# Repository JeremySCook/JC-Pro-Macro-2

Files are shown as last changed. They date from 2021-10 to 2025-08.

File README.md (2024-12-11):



# JC-Pro-Macro-2 Rotary Macro Keypad with GPIO Breakouts

JC Pro Macro 2 macro keyboard and rotary input, with GPIO breakouts. Uses an ATmega32u4 Pro Micro dev board for HID functionality.

Available now on Tindie: https://www.tindie.com/products/jeremycook/jc-pro-macro-2-rotarygpio-macro-keyboard-kit/

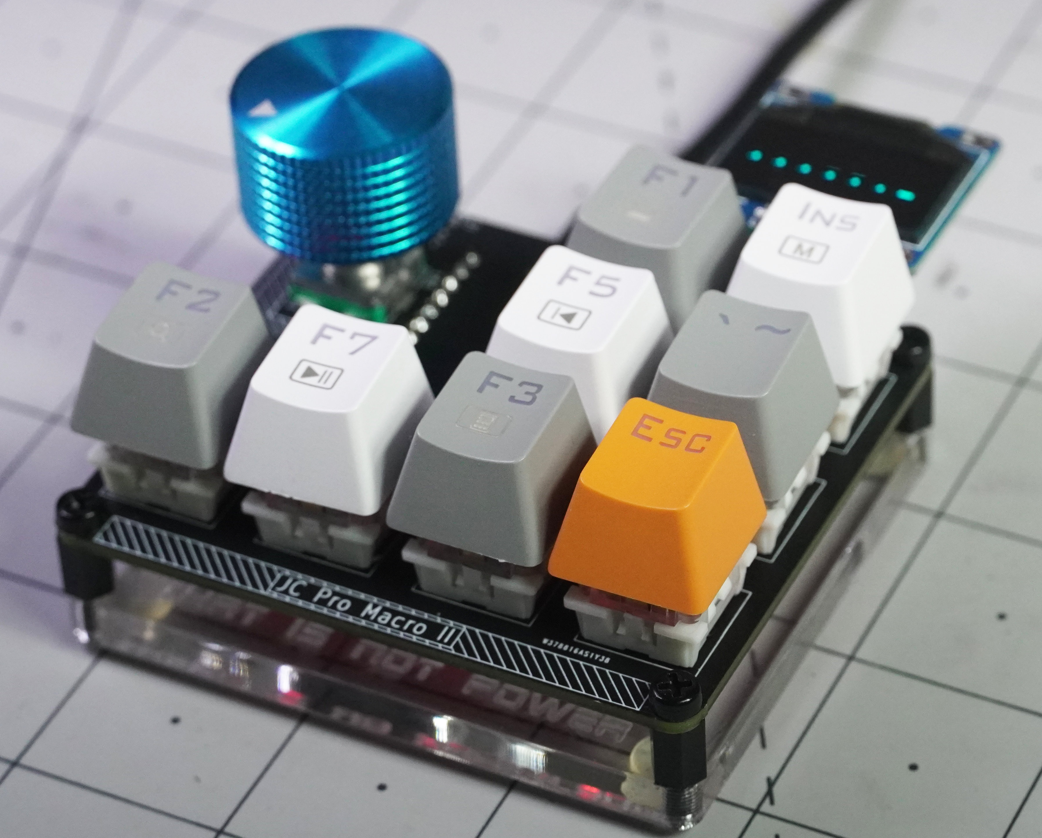
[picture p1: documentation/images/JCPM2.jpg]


Manual: https://github.com/JeremySCook/JC-Pro-Macro-2/tree/main/documentation  

# Intro Video (YouTube):

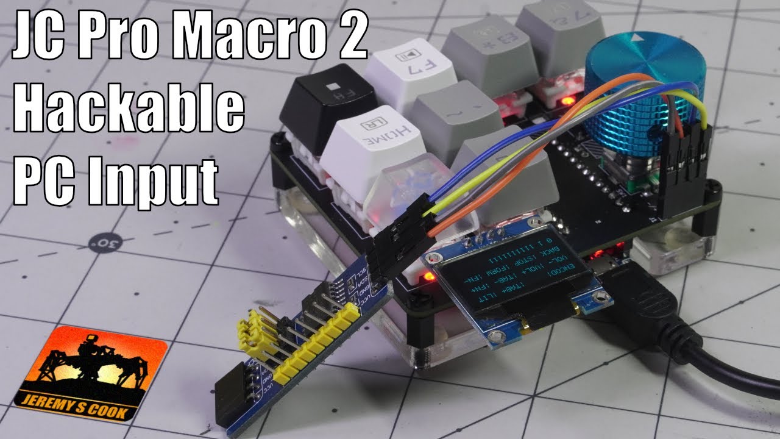
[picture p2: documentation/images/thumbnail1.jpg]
Watch the video (https://www.youtube.com/watch?v=Pz0toa3XK4c)




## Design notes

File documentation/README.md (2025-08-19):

# JCPM 2 User Manual #



If you’re viewing this page, you’ve likely either purchased, or are interested in a JC Pro Macro 2 mechanical shortcut keypad  
(funded on Kickstarter, available soon on Tindie). While it comes with several useful functions:

    • Standard Volume/media/fan control
    • Mouse Jiggler
    • FCPX Helper

The real power of this keyboard, however, is that you can customize it as you see fit.  
You don’t need any sort of program running on your computer to take advantage of it,  
as the computer simply sees it as a secondary keyboard and/or mouse. 

One could argue this makes it quite future proof, however, programming it, as of this writing, will  
require you to use the Arduino IDE. That being said, The design is extremely hackable, and I hope that  
others develop new ways to program and use it, perhaps which I’d never even thought of. This document  
will help you get started.

## Videos ##

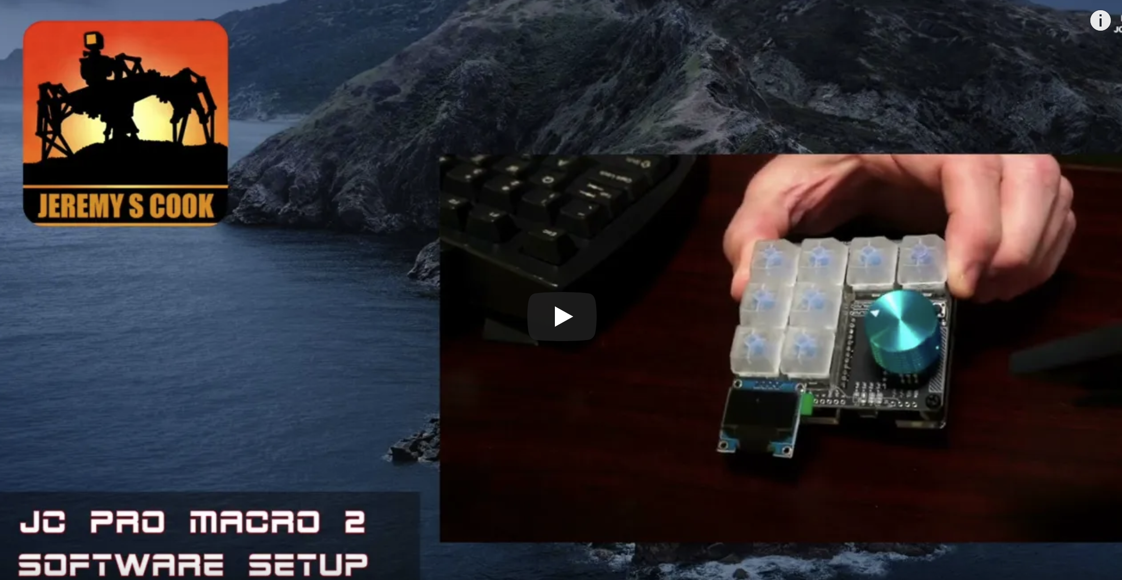
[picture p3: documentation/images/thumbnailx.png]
Watch the video (https://www.youtube.com/playlist?list=PLHdAqwjxcGeRL2wQRV785VI08VL_sdoh7)


## Basic Operation ##

If the JCPM2 came pre-programmed, plug it in via USB and wait a few seconds for it to become active.  
The rotary encoder will control a computer’s volume, while the bottom left three keys are for media control,  
and the two keys directly to the right of the encoder shift through browser tabs. The upper-right key switch  
controls lights under the pad, while the two below that are used to control an external PC-style fan or other  
small load. This can all be customized.

A smaller button on the left of the pad cycles through different modes, the first of which is a random  
mouse jiggler, used to keep a computer awake. The second is set up for Final Cut Pro X, which I enjoy immensely.  
Of course, this may not be useful for you, and can be bypassed in the program.

## Loading a Program ##

First install the Arduino IDE.

**Required Libraries:**

Once the Arduino IDE is installed, you’ll need to add a few libraries (supporting bits of code that you don’t  
directly see, but are used in the program). To do so, navigate to Tools > Manage Libraries, then search for and  
install the following:

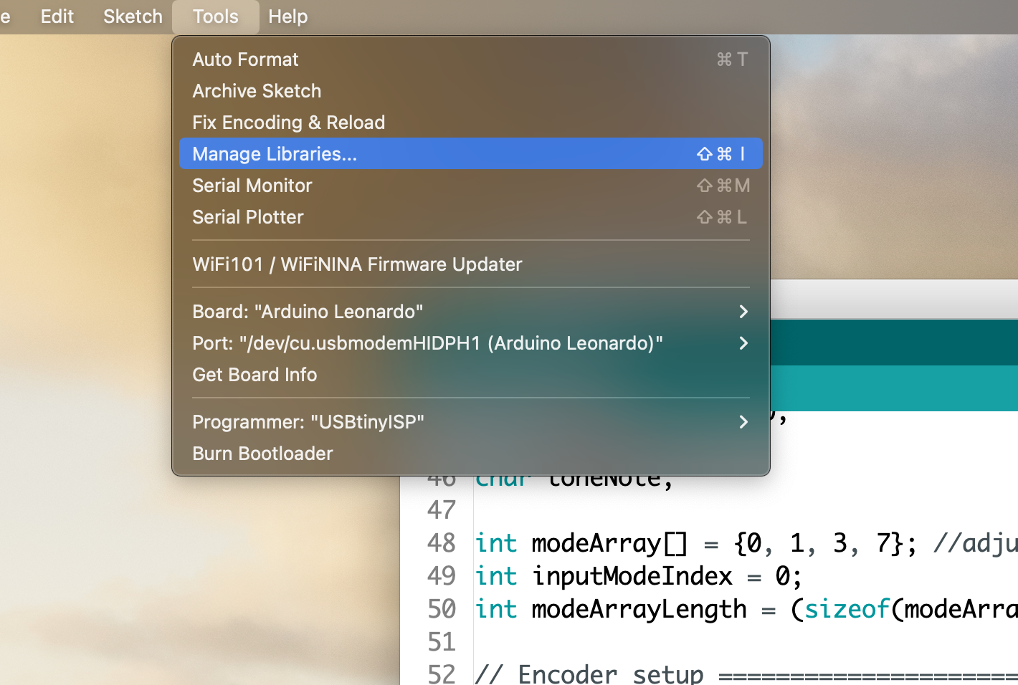
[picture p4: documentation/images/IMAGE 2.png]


    • Encoder (Paul Stoffregen): https://www.pjrc.com/teensy/td_libs_Encoder.html 
    • HID-Project (NicoHood): https://github.com/NicoHood/HID 
    • Adafruit_GFX Library (Adafruit): https://github.com/adafruit/Adafruit-GFX-Library
    • Adafruit SSD1306 (Adafruit): https://github.com/adafruit/Adafruit_SSD1306 
    • Adafruit NeoPixel (Adafruit): https://github.com/adafruit/Adafruit_NeoPixel

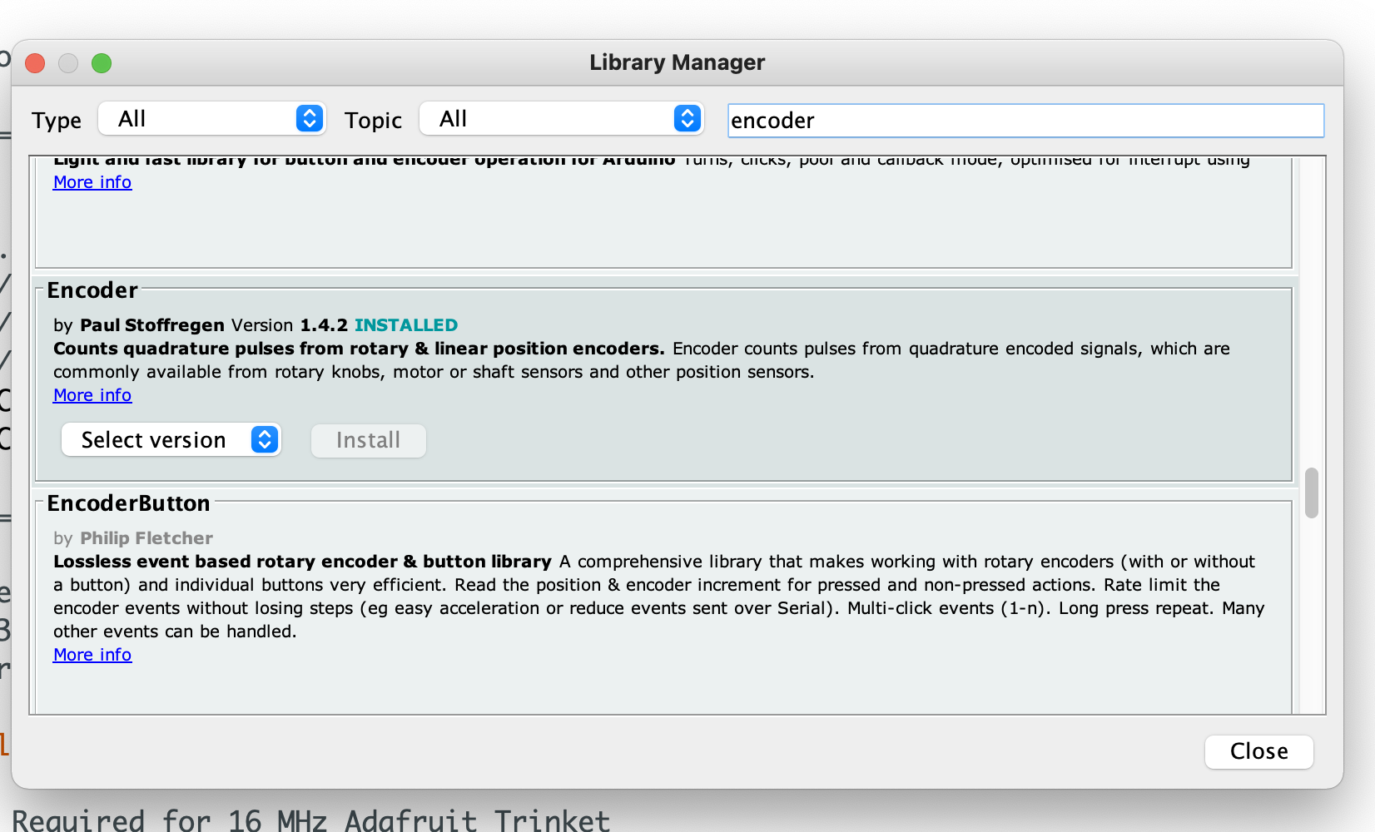
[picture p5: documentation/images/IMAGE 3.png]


Note that several libraries may come up when you search for “Encoder,” “HID-Project,” etc., and you’ll want to  
match up what you’re installing with the author (i.e. Paul Stoffregen). If in doubt, click on the more info link  
and compare it to the list GitHub page, which should be the same.

Additionally, my system has these libraries on it, as well as many others. If you find you're missing a library
please let me know so that I can update this document.

**Open Program and Transfer**

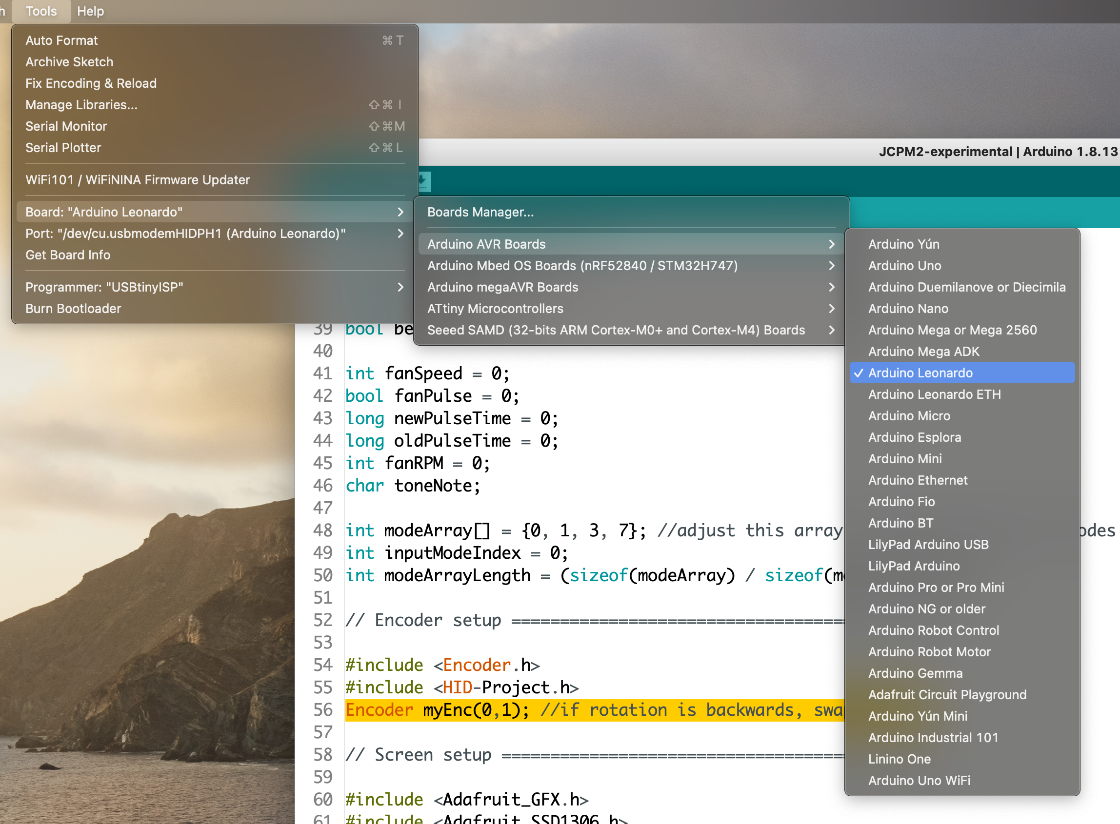
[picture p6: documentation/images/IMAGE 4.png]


Download the JCPM2 program from GitHub, which is a .ino file, or copy/paste it into the Arduino main window.  
Select Tools > Board: > Arduino AVR Boards > Arduino Leonardo, then select Tools > Port and the board that says  
Leonardo. If you’re not sure if you have the right port, unplug the JCPM2 and see what disappears when you try to  
select the port again.

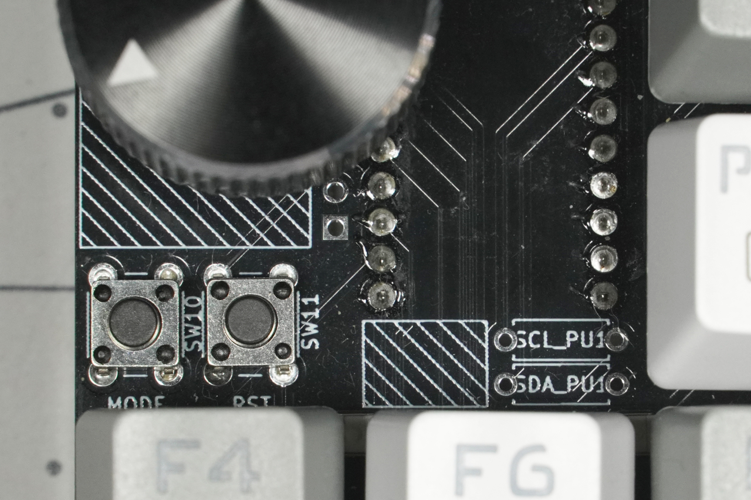
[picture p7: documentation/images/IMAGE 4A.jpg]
IMAGE 4A


Click the arrow/upload button in the top-left of the Arduino IDE, then hit the reset button directly below  
the encoder knob on the device itself right when the Arduino IDE says uploading, or immediately before. Timing
is critical here, so it may take you a few tries to get it correct.

If the JCPM2 has not been programmed yet, the reset procedure may not be needed, but this shouldn’t hurt.

## --Update 2/3/2022 - EASY PROGRAMMING-- ###

If newest code is loaded, thanks to discord user apoxa, includes a programming mode that you can go into by pressing the  
mode button, plus the lower-right keyswitch. In this mode the OLED screen will say "Upload Code!" and you can upload it  
from the Arduino IDE without worrying about physically resetting the board.

## --End Update-- ##

If all is well, you should see some blinking lights on the bottom of the JCPM2, a few seconds for reset, and then normal  
operation (with some extra lights). You’re now at square 1, which can be a very good thing if your subsequent modifications 
are incorrect.

## The Standard Program ##

While this won’t cover ever aspect of the JCPM2 code, the items below will address the highlights that you’ll need to know when  
making/modifying your macro pad. The HID functions (i.e. what keys do) are largely defined in this layout listing,  
so be sure to poke around there if there is something you'd like your JCPM2 to do. That HID libray was instrumental  
in getting the JCPM 2 functional.

    • Line 48: int modeArray[] = {0, 1, 3, 7};	Dictates the sequence of menu items. 0 is the standard 
    bootup screen, 1 is the mouse jiggler, and 7 is a KiCad mode I’ve been working on. If you wanted  
    to only have the bootup then mouse jiggler, it’d read as “{0,1}”.
    
    • Line 56: Encoder myEnc(0,1);	If your encoder is functioning backwards, change this around to  
    “(1,0).” Some encoders are wired differently than others.
    
    • Lines 95 – 109:	You likely won’t have to mess with this, however, note the delay at the beginning  
    to facilitate programming. Take that out/reduce at your own risk. Lines below that show the configuration  
    of the Pro Micro pins, and that they are set up as pullup inputs – i.e. 1 (HIGH) means a button is not pressed,  
    while 0 (LOW) means a button is pressed.
    
    • Lines 186 – 207:	Select input mode correlates with line 48, and passes the code along to the correct  
    function in the sequence. It also sets the initial key lighting so that it immediately correlates with the  
    mode you’re in.
    
    • Lines 215 – 714:	The meat of the program. As shown in like 240, if SW6 == 0, that is pressed per logic  
    discussed above, then do whatever is between the curly braces {}. Line 229 deals with the encoder rotation, in  
    this case “1” meaning a rotational pulse. There’s a bit of code to control the lights correctly, but what  
    you’ll want to modify is line 230 if a different input is needed. Key light colors are modified in line 234.
    
    • Lines 718 – 832:	Defines what the OLED screen shows depending on what input mode the JCPM2 is in. It’s  
    mostly static text to show which button/knob does what, however, as shown in the default/volume screen, it can  
    change dynamically if you so desire. Each screen segment is called at the end of it’s corresponding function in  
    lines 215-714. For example, “screenVolume();” on like 285 calls the corresponding function on line 716.
    
Hopefully that give you enough info to start hacking away at the code. Line numbers should be treated as approximate, as  
this document likely won’t always be updated. If you’d like to share what you’ve come up with, or ask a question, please  
chime in on Discord: https://discord.gg/7DkuTrq8

## Hardware/Ergonomics ##

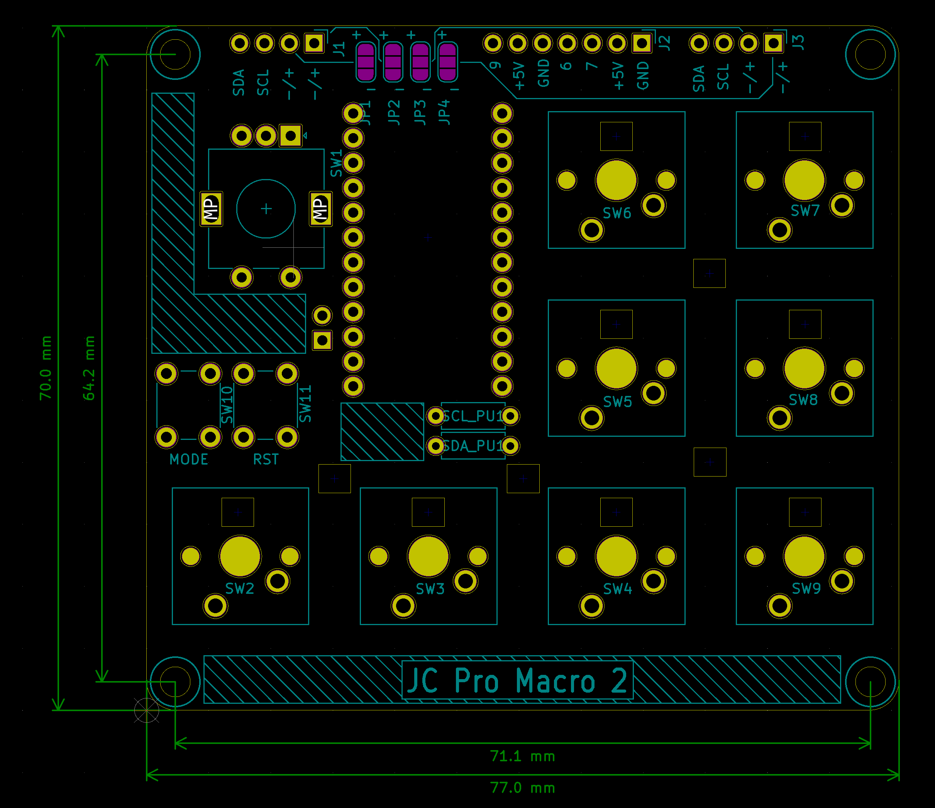
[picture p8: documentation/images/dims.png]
dims


As for which button does what, the above image shows the switch labeling arrangement (as well as dimensions if you'd like  
to design hardware around it.

Working with FCPX, I’ve found that keeping your three most used keys on the bottom-left and keeping your index, middle, 
and ring fingers there as a sort of home position works really well. As far as ergonomics, you may wish to have your wrist  
at a slight angle, and I put a 3D-printable base up here that puts it at 3 degrees.

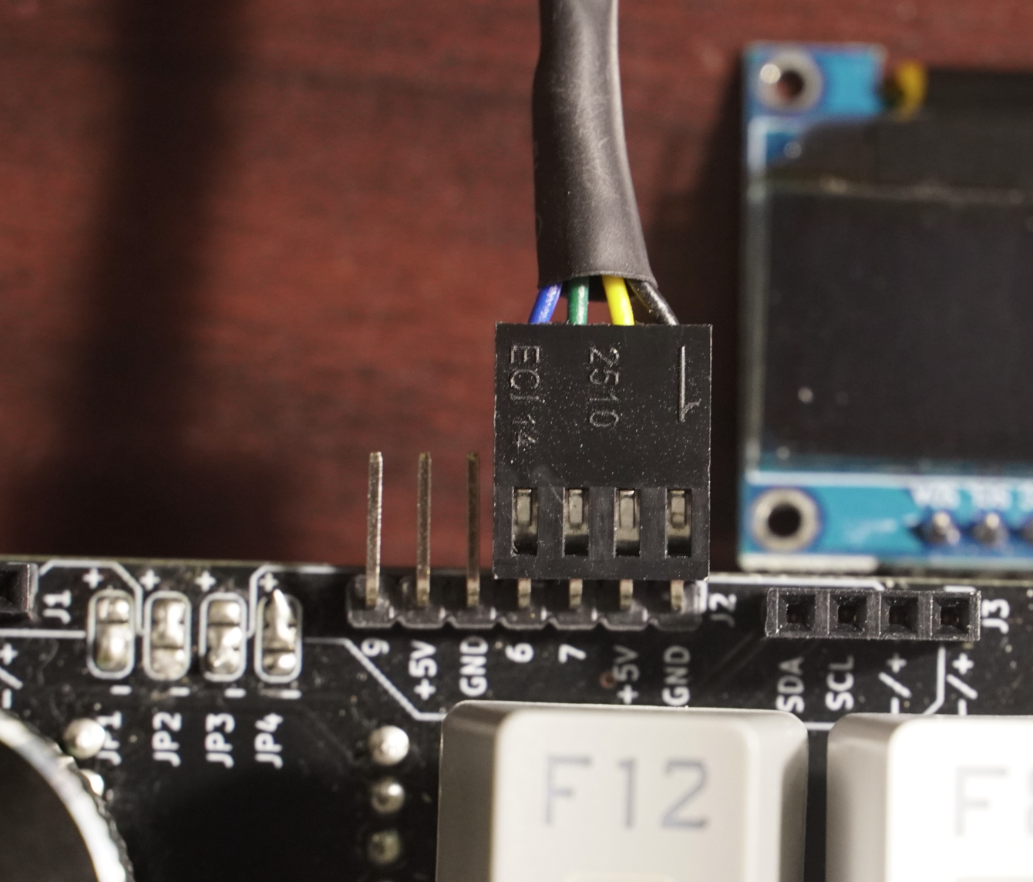
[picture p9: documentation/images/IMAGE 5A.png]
IMAGE 5A


The devide is capable of controlling a small PC fan. A 12V PWM PC fan will work, but is underpowered and tends to be slow. I  
suggest instead using a 5V PWM fan, such as this one by Noctua (Amazon Affiliate). It’s fairly expensive, and is colored  
like a brownie, but it works quite well. Just plug it in to the headers as shown, and with the standard code in bootup  
mode the middle-rightmost key will turn it up, while the key below that turns it down.

Of course, this is but the built-in functionality. These and other pins are broken out to allow you to experiment with  
external devices. This is, of course, at your own risk.

## Jumper/AUX pins info

J1 and J3 are both setup to support standard SSD1306 OLED screens, and function identically. +/- are set based on JP1, JP2, JP3, and JP4, and can be set independently between J1 and J3. SDA and SCL are serial data and serial clock respectively for I2C connections.  
Two screens or different devices can be used on the different jumpers, theoretically at the same time.  
J2 - AUX pinout for Pro Micro board - pins 9, 6, 7, positive voltage and GND. My current setup reads at 3V3, not 5V, which is likely a product of the dev board I'm using.
SCL_PU1 and SDA_PU1 are optional pullup resistors for the SCL and SDA lines. Not typically needed.  
J4 - optional capacitor can be placed here

## Tips: ##

**If Programming Doesn’t Work - Need to update**

## Future Ideas and Notes ##

Would likely be possible to keep a standard program on the JCPM2, while modifying behavior through a program like  
AutoHotkey.

Adafruit's Pro Mirco-format KB2040 board should be compatible with the  
JC Pro Macro 2 I'm not sure if or when I'll get a chance to try it out, but would certainly be interesting.

The device was developed for MacOS, but the standard shortcuts should also work for Windows PCs. FCPX won't be useful
with PCs of course. If you do poke around in the code, there are several additional modes that come disabled in the
program, but may not be quite as useful or developed.

My sincere hope is that a community will develop around this device and that others develop  
applications and hardware for it. If there's anything I can do to help **you** pull off a fun hack or improvement,
please get in touch. My email is hi at jeremyscook.com, or Twitter and Discord are also good ways to get in touch.




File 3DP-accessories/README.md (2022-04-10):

# 3D Printed accessories for the JCPM2 #

Lots of acessories to personalize your JCPM2!

## External Print Listings ##

Screen support by orthodoxmonster: https://www.thingiverse.com/thing:5228879

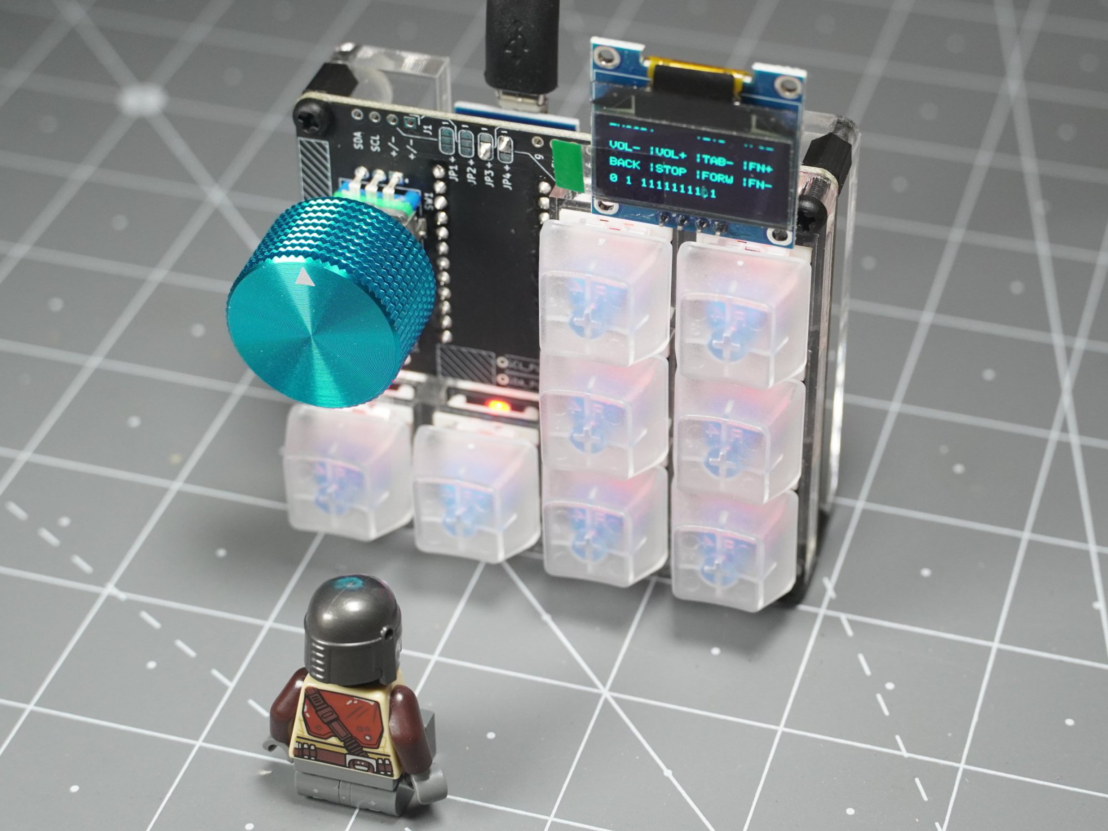
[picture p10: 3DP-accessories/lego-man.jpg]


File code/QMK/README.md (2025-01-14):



New experimental macro pad firmware [based on QMK](https://qmk.fm/) - Using this firmware should make it
much easier to modify the keymap and customiza things to your liking. [See setup](https://github.com/JeremySCook/JC-Pro-Macro-2/tree/main/code/QMK/setup)
for more info on getting this firmware working.

See the setup folder for instructions on how to install and modify this firmware.

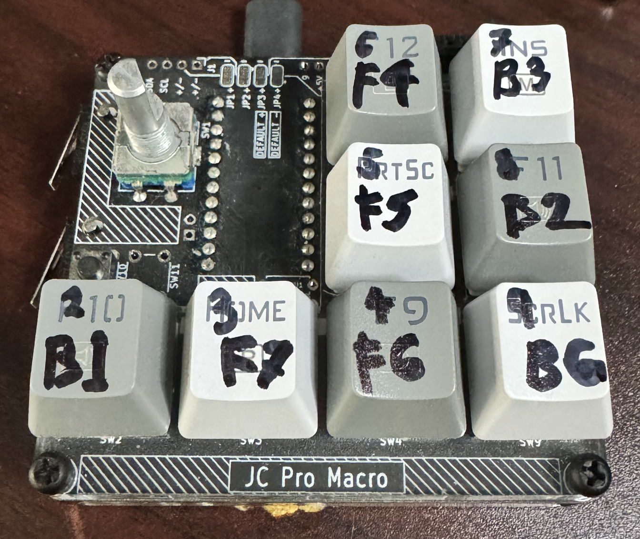
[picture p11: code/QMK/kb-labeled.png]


Above image: Keycaps labeled with ATmega32U4 pin numbers where each is connected (e.g. B1). These pin numbers are
needed for QMK definition. Below is a schematic which should be largely correct for the JCPM2s out there today.

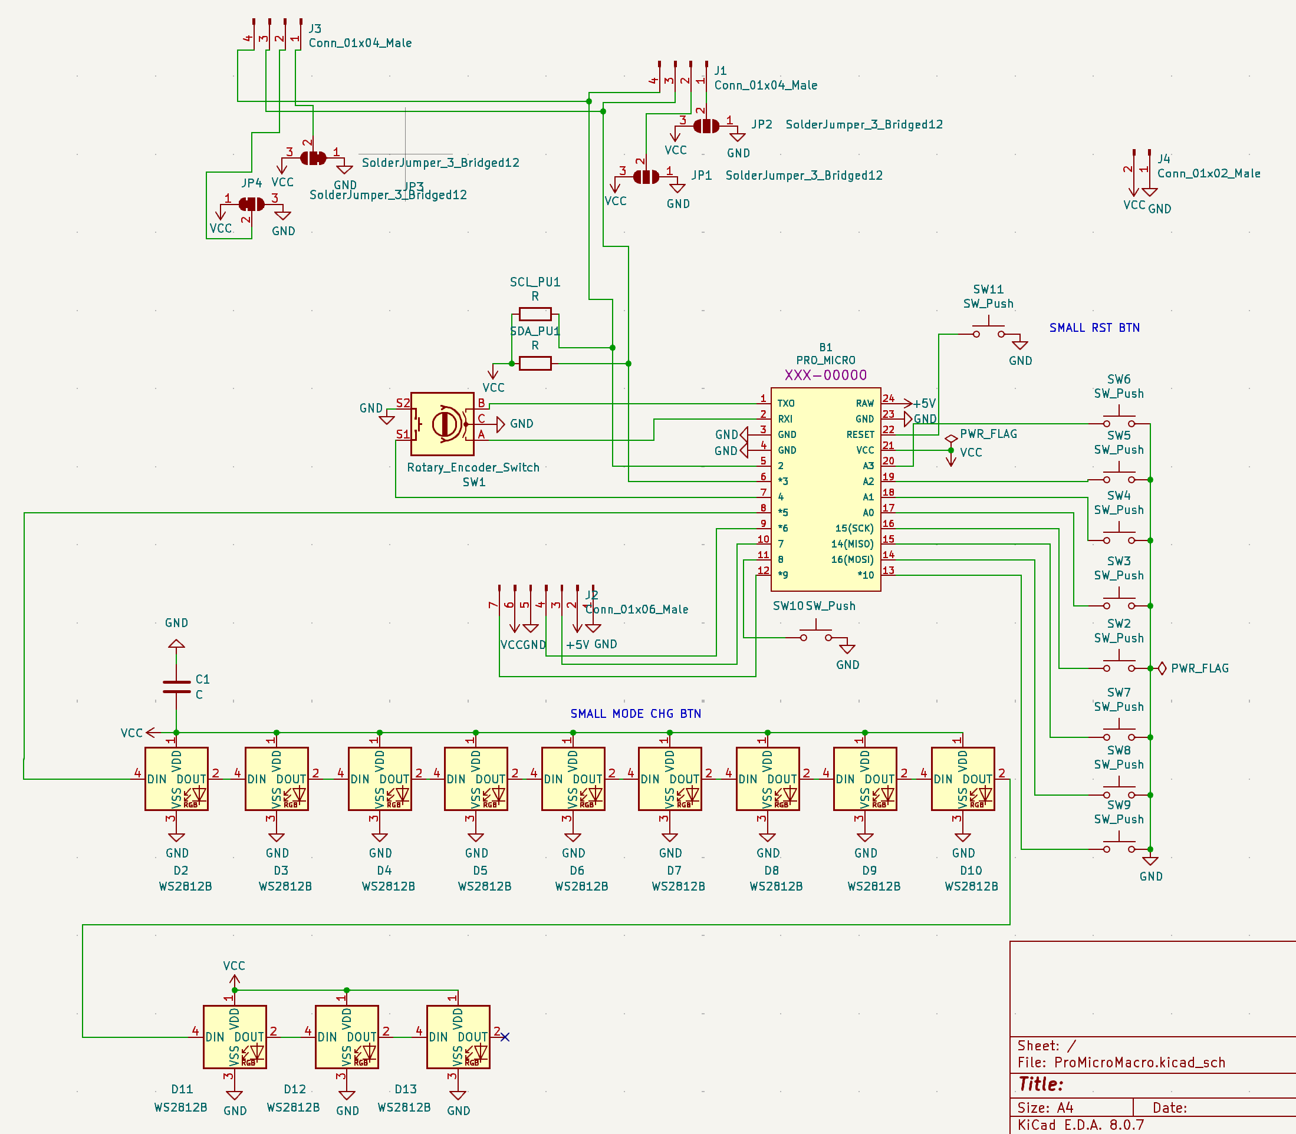
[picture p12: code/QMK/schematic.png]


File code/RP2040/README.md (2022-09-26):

Very experimental code using an Adafruit Kee Boar RP2040 board with the JCPM2.

Available from Adafruit here: https://www.adafruit.com/product/5302
or via Amazon (Affiliate - more expensive, but Prime shipping): https://amzn.to/3Sg97M5

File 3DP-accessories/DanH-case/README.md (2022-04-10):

1-piece enclosure created by Dan H.

[See here](https://github.com/JeremySCook/JC-Pro-Macro-2/tree/main/3DP-accessories/DanH-keycaps) for keycaps

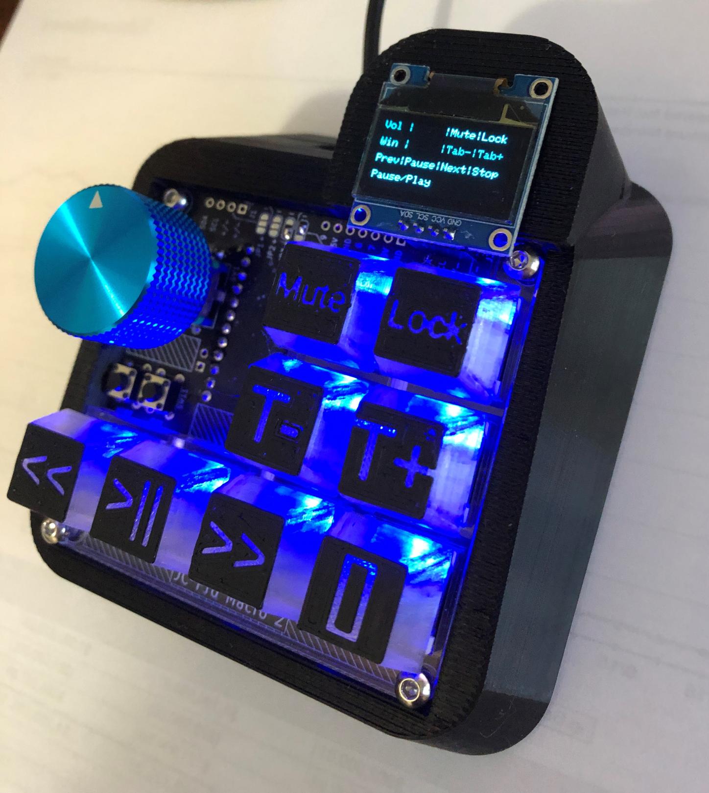
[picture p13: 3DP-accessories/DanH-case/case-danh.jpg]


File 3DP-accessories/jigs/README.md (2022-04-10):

Jigs to make assembly easier.

Jig-JCPM2-KeySwitch-Jig-NoRetainer.stl has not been tested, however, should work
to line up keyswitches, and provide spacing for EC-11 encoder without keyswitch retainer installed.

Jig-EC-11-Helper.stl should not be needed if using the either KeySwitch jig, however
is a much shorter print, and could be useful in a variety of situations generally.

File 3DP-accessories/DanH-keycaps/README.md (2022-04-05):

Key Caps by Dan Hastings, including OpenSCAD files for modification.

Originally printed face down, with color change at .5mm.

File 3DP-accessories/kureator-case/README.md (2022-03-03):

Case designed by kureator - sanded .125 inch acrylic in middle

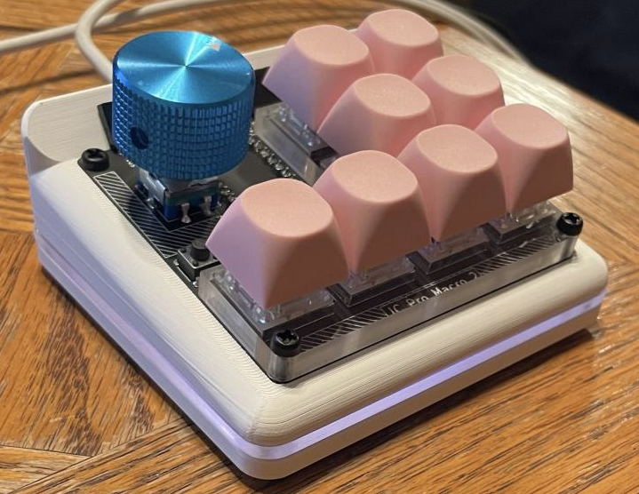
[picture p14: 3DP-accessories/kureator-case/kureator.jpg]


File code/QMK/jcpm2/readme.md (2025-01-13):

# jcpm2

jcpm2

*A short description of the keyboard/project*

* Keyboard Maintainer: [jeremyscook](https://github.com/jeremyscook)
* Hardware Supported: *The PCBs, controllers supported*
* Hardware Availability: *Links to where you can find this hardware*

Make example for this keyboard (after setting up your build environment):

    make jcpm2:default

Flashing example for this keyboard:

    make jcpm2:default:flash

See the [build environment setup](https://docs.qmk.fm/#/getting_started_build_tools) and the [make instructions](https://docs.qmk.fm/#/getting_started_make_guide) for more information. Brand new to QMK? Start with our [Complete Newbs Guide](https://docs.qmk.fm/#/newbs).

## Bootloader

Enter the bootloader in 3 ways:

* **Bootmagic reset**: Hold down the key at (0,0) in the matrix (usually the top left key or Escape) and plug in the keyboard
* **Physical reset button**: Briefly press the button on the back of the PCB - some may have pads you must short instead
* **Keycode in layout**: Press the key mapped to `QK_BOOT` if it is available

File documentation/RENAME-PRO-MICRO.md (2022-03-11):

## Here is how to rename your device ##

So the keyboard no longer displays as "Arduino Leonardo" on Device Manager, but instead anything you want. 

* Close down the Sketch IDE

* Go to C:\Users{YOUR USERNAME}\AppData\Local\Arduino15\packages\arduino\hardware\avr\1.8.5

* Open Boards.txt

* Locate (Ctrl+F) "Arduino Leonardo"

* Update leonardo.name=Arduino Leonardo to something else, I named mine: leonardo.name=Macro Keyboard

* Also locate this line leonardo.build.usb_product="Arduino Leonardo"  
  (I updated mine to:leonardo.build.usb_product="Macro Keyboard")

* Open Sketch and upload the JCPM latest build from Jeremy to your device using his procedures in the README. 

* Device is now "Macro Keyboard"

Big thanks to Thanks to [Ben Rogers](https://github.com/BenRogersWPG) for working this procedure out!

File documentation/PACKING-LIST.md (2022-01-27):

List of items to be put in JCPM2 kits WIP

# STANDARD KIT #

    • Main PCB
    • Pro Micro
    • Base
    • 8 key switches
    • 8 keycaps
    • Basic or premium knob
    • Parts Kit*

## PARTS KIT CONTENTS WT = .31 - .32 Oz ##

    • Socket
    • (2) buttons
    • Encoder
    • Female header, 4 pin
    • bumpers
    • (4) standoffs
    • (4) short screws
    • (3) long screws

## OPTIONS ##

    • OLED Screen
    • Premium knob + Allen Key
    • Keyswitch Plate
    • USB Cable

## Procedure ##

    • Put all parts in for standard order except knob
    • Add knob and options per order
    
## Procedure ##
asdfsad

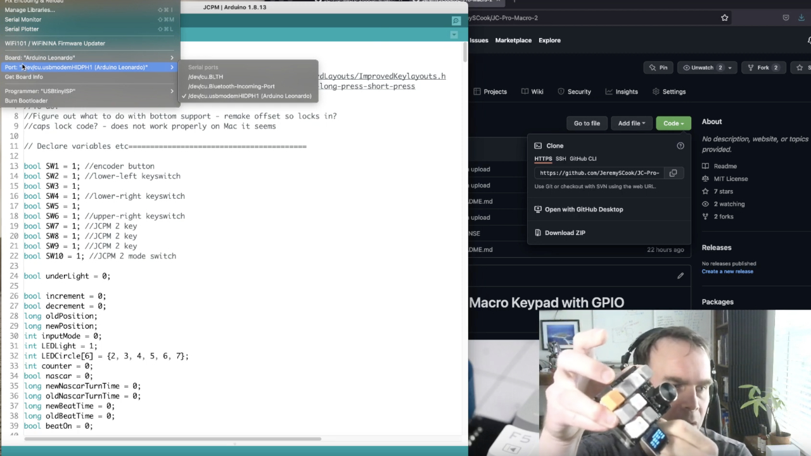
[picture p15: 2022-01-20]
documentation/images/thumbnailx.jpg

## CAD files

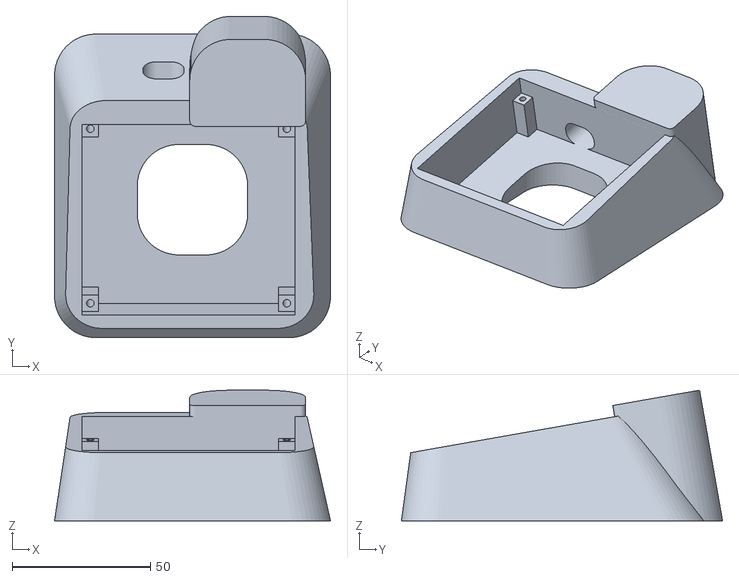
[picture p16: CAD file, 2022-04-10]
3DP-accessories/DanH-case/Case_V1.1.stl
100.0 x 116.4 x 47.3

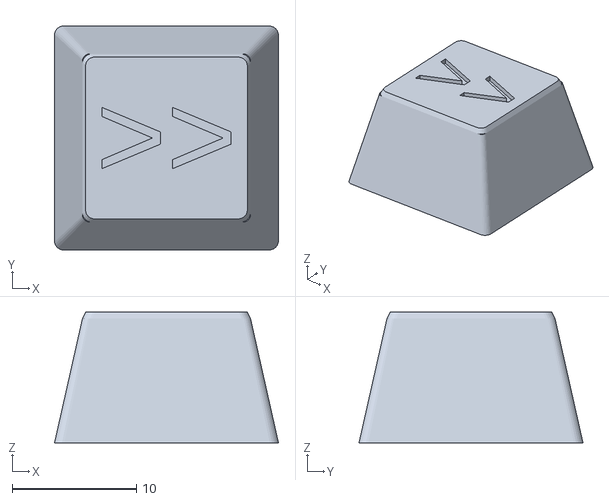
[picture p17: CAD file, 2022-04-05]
3DP-accessories/DanH-keycaps/Cap_Next.stl
18.0 x 18.0 x 10.5

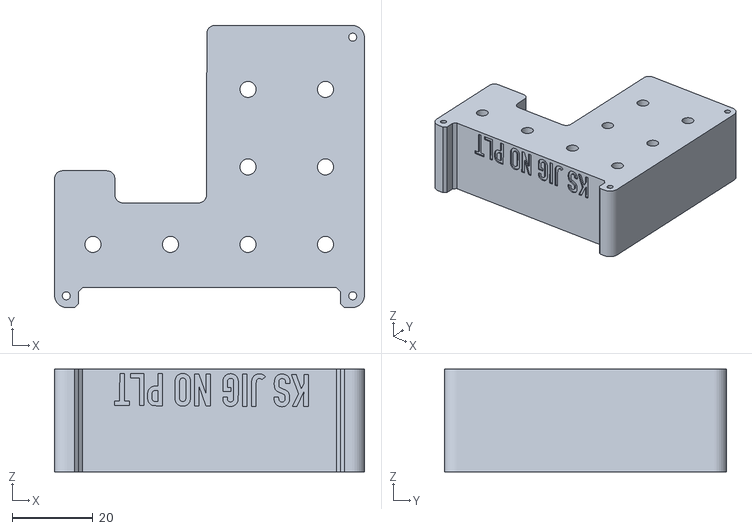
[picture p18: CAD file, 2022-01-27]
3DP-accessories/jigs/Jig-JCPM2 -KeySwitch-NoRetainer.stl
77.0 x 70.0 x 25.5

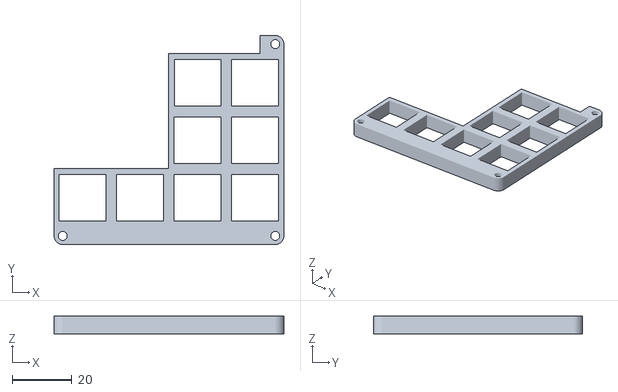
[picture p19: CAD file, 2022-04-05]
3DP-accessories/keyswitch-separator-grid.stl
77.0 x 70.0 x 6.00

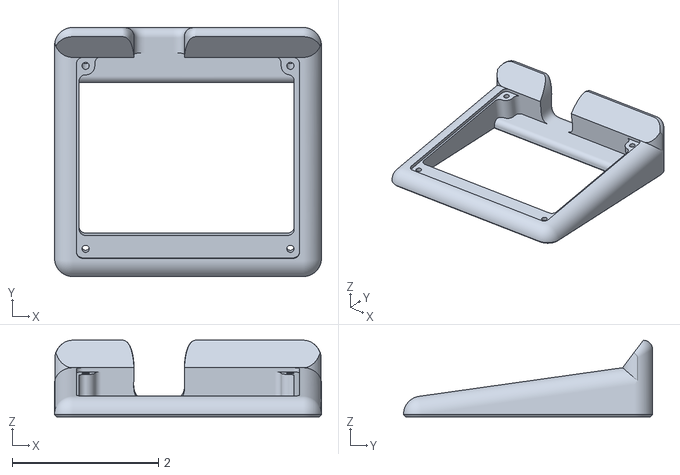
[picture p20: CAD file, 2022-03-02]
3DP-accessories/kureator-case/JCMacro2_Case_V3_-_Angled_Stand1.stl
3.65 x 3.41 x 1.05

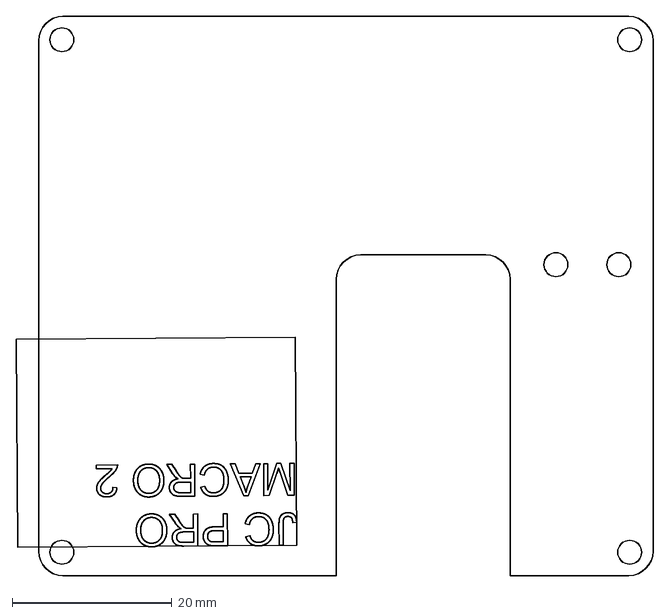
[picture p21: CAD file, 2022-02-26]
mechanical/base-no-lettering.dxf
79.8 x 70.0 mm

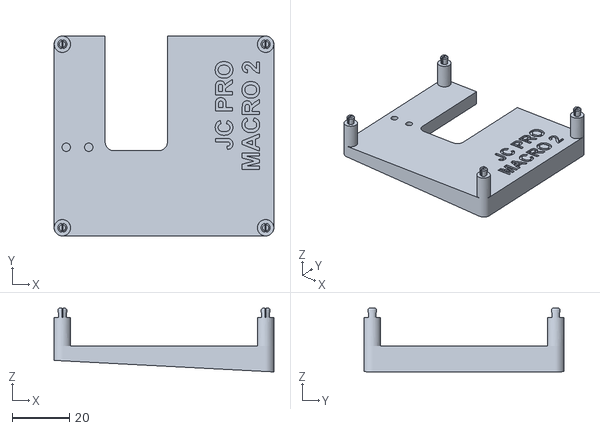
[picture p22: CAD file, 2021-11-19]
3DP-accessories/JCPM2-base-ergo-3deg.stl
77.0 x 70.0 x 22.3

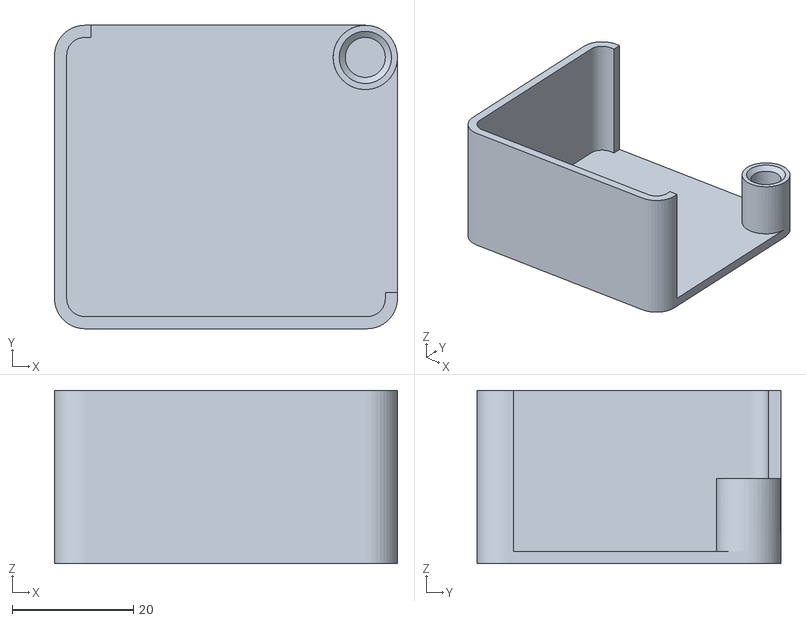
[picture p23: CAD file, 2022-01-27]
3DP-accessories/jigs/Jig-EC-11-Helper.stl
56.5 x 50.0 x 28.5

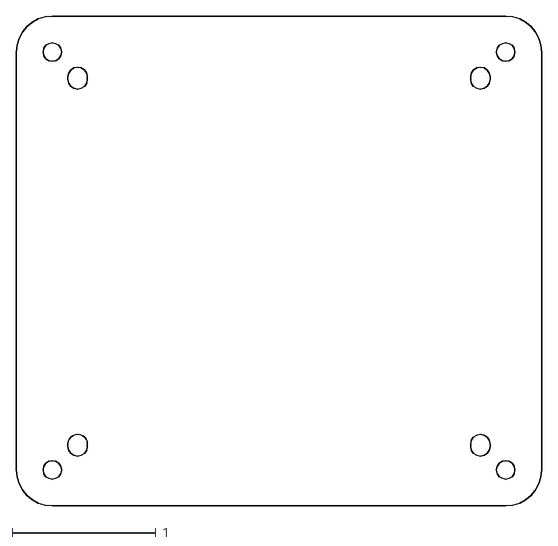
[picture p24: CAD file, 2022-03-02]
3DP-accessories/kureator-case/JCMacro2_Case_V3_-_Acrylic1.dxf
3.65 x 3.41

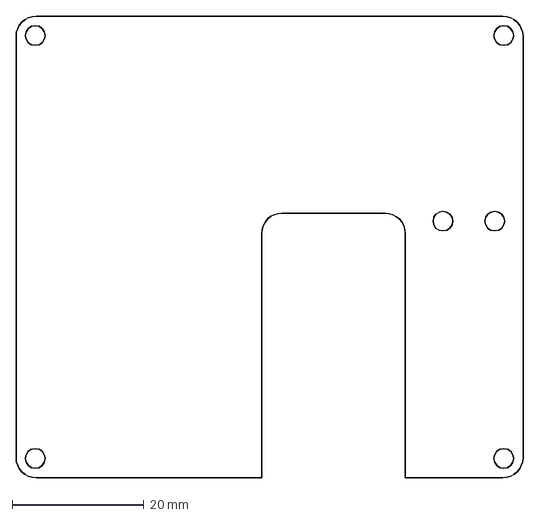
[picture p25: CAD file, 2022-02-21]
mechanical/base.dxf
77.0 x 70.0 mm

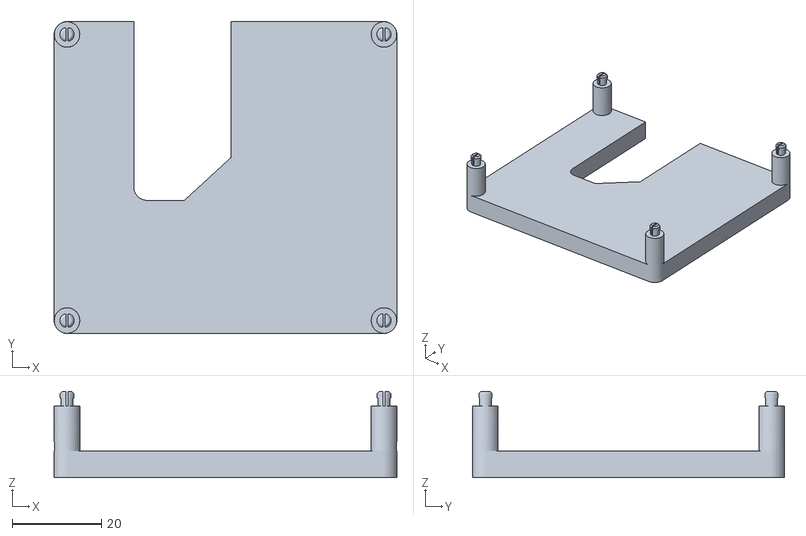
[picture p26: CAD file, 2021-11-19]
3DP-accessories/JCPM2-base.stl
77.0 x 70.0 x 19.3

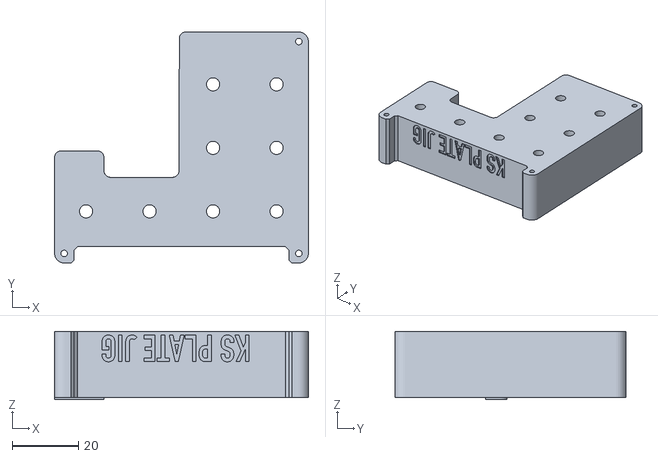
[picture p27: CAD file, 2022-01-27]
3DP-accessories/jigs/Jig-JCPM2-KeySwitch-Retainer.stl
77.0 x 70.0 x 20.7

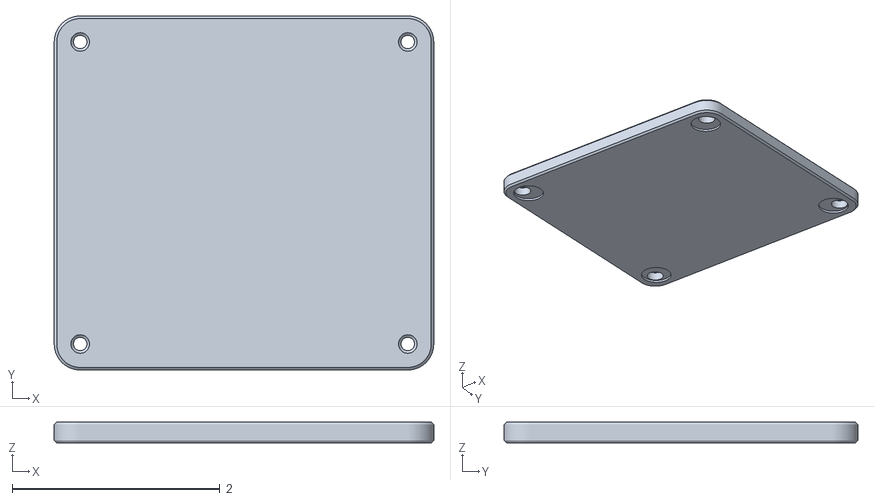
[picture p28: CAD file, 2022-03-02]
3DP-accessories/kureator-case/JCMacro2_Case_V3_-_Base_Plate2.stl
3.65 x 3.41 x 0.2

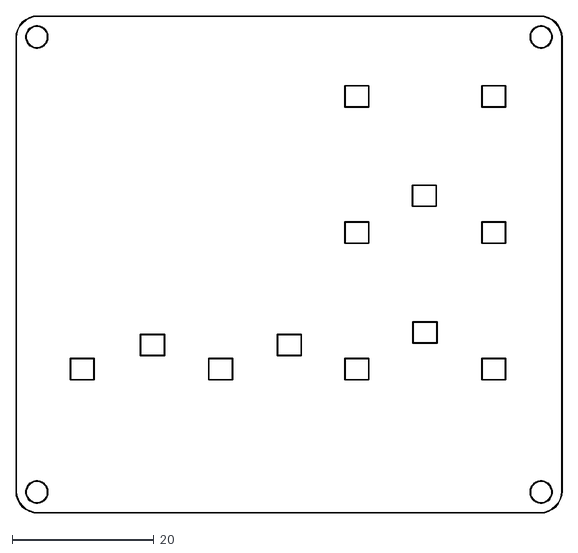
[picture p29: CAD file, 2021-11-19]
mechanical/JC Pro Macro 2 Board Cuts.dxf
77.0 x 70.1

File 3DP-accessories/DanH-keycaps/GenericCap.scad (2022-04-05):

$fn=25;

Outside_Width=18;
Outside_Height=10;
Spindle_Diameter=5.25;
Line_Width=1.15;
Line_Length=4;
Wall_Thickness=1.5;
Top_Width=13.5;
Symbol_Thickness=0.5;
Key_Symbol="9";


// Top Layer
translate([0,0,Outside_Height])
difference(){
Capshape(Symbol_Thickness,Top_Width,Wall_Thickness,Top_Width-Symbol_Thickness);
// Symbol on Key Cap
linear_extrude(height=Symbol_Thickness)
text(Key_Symbol,valign="center",halign="center");
}

// Basic Cap Shape
difference(){
Capshape(Outside_Height,Outside_Width,Wall_Thickness,Top_Width);
// Hollow it out
Capshape(Outside_Height-Wall_Thickness,Outside_Width-Wall_Thickness*2,Wall_Thickness,Top_Width-Wall_Thickness*2);
}

difference(){
// Spindle
cylinder(h=Outside_Height,d=Spindle_Diameter);
// Slots
union(){
translate([Line_Width/-2,Line_Length/-2,0])
cube([Line_Width,Line_Length,Outside_Height-Wall_Thickness]);
translate([Line_Length/-2,Line_Width/-2,0])
cube([Line_Length,Line_Width,Outside_Height-Wall_Thickness]);
}
}


module Capshape(Height,Width,Thickness,Top){
linear_extrude(height=Height,scale=Top/Width){
translate([0-Width/2,0-Width/2,0]){
hull(){
translate([Thickness/2,Thickness/2,0])
circle(d=Thickness);
translate([Width-Thickness/2,Thickness/2,0])
circle(d=Thickness);
translate([Width-Thickness/2,Width-Thickness/2,0])
circle(d=Thickness);
translate([Thickness/2,Width-Thickness/2,0])
circle(d=Thickness);
}
}
}
}

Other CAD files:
3DP-accessories/DanH-keycaps/Cap_Prev.stl
3DP-accessories/DanH-keycaps/Cap_Tab_Prev.stl
3DP-accessories/DanH-keycaps/Cap_7.stl
3DP-accessories/jigs/Jig-ProMicro-Solder.stl
3DP-accessories/DanH-keycaps/Cap_1.stl
3DP-accessories/DanH-keycaps/Cap_2.stl
3DP-accessories/DanH-keycaps/Cap_3.stl
3DP-accessories/DanH-keycaps/Cap_4.stl
3DP-accessories/DanH-keycaps/Cap_5.stl
3DP-accessories/DanH-keycaps/Cap_6.stl
3DP-accessories/DanH-keycaps/Cap_8.stl
3DP-accessories/DanH-keycaps/Cap_9.stl
3DP-accessories/DanH-keycaps/Cap_Lock.stl
3DP-accessories/DanH-keycaps/Cap_Mute.stl
3DP-accessories/DanH-keycaps/Cap_Play_Pause.stl
3DP-accessories/DanH-keycaps/Cap_Stop.stl
3DP-accessories/DanH-keycaps/Cap_Tab_Next.stl
3DP-accessories/kureator-case/JCMacro2_Case_V3.step
3DP-accessories/kureator-case/JCMacro2_Case_V3.stl

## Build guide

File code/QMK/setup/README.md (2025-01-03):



To install the firmware hex file, install QMK toolbox https://github.com/qmk/qmk_toolbox and select your firmware (you can use jcpm2test_default.hex found in the QMK directory). Plug in your JCPM2 and Double-click the reset button. Then press flash in QMK Toolbox, or check the Auto-Flash box to have it flash when it recognizes your JCPM2.

jcpm2-setup1a

To modify QMK firmware, first set up your build environment via instructions found here: https://docs.qmk.fm/newbs_getting_started

jcpm2-setup1

Copy the jcpm2test folder into the keyboard directory. To Modify keycodes, open `keymap.c` in the `keymaps/default` directory with a plain text editor like CotEditor for MacOS.
Change the definitions around for the keys and encoder as definited in [the QMK keycodes Overview https://github.com/qmk/qmk_firmware/blob/master/docs/keycodes.md

For example, if you want the bottom-left key in the startup keymap to type `A` change `KC_MPRV` to `KC_A` in line 42 as shown below.
If you'd like to change the encoder operation around for the startup keymap `(_LAYER0)`, change `KC_KB_VOLUME_DOWN` or `KC_KB_VOLUME_UP`
to another keycode, such as `KC_A`.

jcpm2-setup2

Once modifications are made, save the file and complie by running: `qmk compile -kb jcpm2test -km default` in a terminal. Flash the resulting hex file as outlined above.

The eventual goal is to get JCPM2 firmware set up in the QMK configurator https://config.qmk.fm/ That will likely take
a bit more yak shaving, but I believe what I have here is a good step in that direction and useful as-is.

As with the current firmware, this guide is rough and has only been tested in MacOS with the build environment installed. If you have success flashing in Linux or Windows, and/or if you have any suggestions, tips, or otherwise want to contribute, do let me know here or email me: hi at jeremyscook.com

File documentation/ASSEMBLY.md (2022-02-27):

# JCPM 2 User Manual (Work-in-Progress)#

Thanks for purchasing a JC Pro Macro 2 assembly kit! While it's possible to solder items in a different order, following  
these steps should make it a bit easier.

## Step 0 ##

The JC Pro macro can be assembled with little more than a soldering iron or screwdriver. That being said, I've developed
several 3D-printable jigs to help in the process, [available here](https://github.com/JeremySCook/JC-Pro-Macro-2/tree/main/3DP-accessories)

## Step 1 Pro Micro Assembly/Text ##

Remove the Pro Micro board from its packaging, plug in to computer and program per [main use manual](https://github.com/JeremySCook/JC-Pro-Macro-2/blob/main/documentation/README.md).  
If done at the beginning, this ensures that your Pro Micro board is working correctly before any potential issues with  
overall assembly. Once successful, solder legs on. It can be helpful to use a breadboard as a jig, or use the 3D-printable  
jig found in the printing directory.

## Step 2 ##

Solder Pro Micro Socket to bottom.

## Step 3 Solder key switches in place. ##

Remove any protective covering, and place keyswitch retainer on top of keyboard PCB if purchased, then place key switches  
in their through holes. Helpful to put in correct through holes upright, cover with a flat object (perhaps a piece of cardboard)  
then flip onto a flat surface. Solder keys, paying attention that everything is aligned correctly, especially if not  
using a retainer.

## Step 4 Solder Mode/Reset buttons and encoder ##

Pop mode/reset buttons into place on top of PCB, along with encoder. Encoder may take some finagling to get all leads
into place, but should fit. Flip and solder. It may be helpful to cut into a box or similar to allow encoder to hang down  
while resting on the keys. Alternatively, one of the printed jigs can be very helpful here.

## Step 4 A Solder Optional OLED Screen ##

Solder female 4-pin header to through-holes on right. Solder rightmost pads to match ghe Vcc/Gnd configuration of OLED  
screen, most commonly: JP3 middle to +, JP4 middle to -.

## Step 5 Mechanical Assembly ##

Most of this is fairly straightforward, however, standoff installation in base involves a press fit that may not be  
immediately evident. First, 

Remove any protective covering. Press all four standoffs in lightly in the side that says "JC Pro Macro 2." Turn over, and  
press each standoff in individually, ensuring they bottom out. Place the assembled PCB on top and screw in, using long screws
over retainer plate.

Press on basic knob, or install premium knob using allen key. Plug in, and if programmed in earlier step, you're good to go!

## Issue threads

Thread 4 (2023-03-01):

I'm trying to upload code but it is not possible due to error

ayangwithb, 2023-03-01:
I set board&port but it is not available to upload the sample source code
Board : Arduino Leonardo

```
avrdude: Version 6.3-"C:\Users\y_ann\AppData\Local\Arduino15\packages\arduino\tools\avrdude\6.3.0-arduino17/bin/avrdude" "-CC:\Users\user\AppData\Local\Arduino15\packages\arduino\tools\avrdude\6.3.0-arduino17/etc/avrdude.conf" -v  -patmega32u4 -cavr109 "-PCOM4" -b57600 -D "-Uflash:w:C:\Users\user\AppData\Local\Temp\arduino\sketches\121546B5B3FFF953900FDF8E8047870B/JCPM.ino.hex:i"
20190619
         Copyright (c) 2000-2005 Brian Dean, http://www.bdmicro.com/
         Copyright (c) 2007-2014 Joerg Wunsch

         System wide configuration file is "C:\Users\user\AppData\Local\Arduino15\packages\arduino\tools\avrdude\6.3.0-arduino17/etc/avrdude.conf"

         Using Port                    : COM4
         Using Programmer              : avr109
         Overriding Baud Rate          : 57600
         AVR Part                      : ATmega32U4
         Chip Erase delay              : 9000 us
         PAGEL                         : PD7
         BS2                           : PA0
         RESET disposition             : dedicated
         RETRY pulse                   : SCK
         serial program mode           : yes
         parallel program mode         : yes
         Timeout                       : 200
         StabDelay                     : 100
         CmdexeDelay                   : 25
         SyncLoops                     : 32
         ByteDelay                     : 0
         PollIndex                     : 3
         PollValue                     : 0x53
         Memory Detail                 :

                                  Block Poll               Page                       Polled
           Memory Type Mode Delay Size  Indx Paged  Size   Size #Pages MinW  MaxW   ReadBack
           ----------- ---- ----- ----- ---- ------ ------ ---- ------ ----- ----- ---------
           eeprom        65    20     4    0 no       1024    4      0  9000  9000 0x00 0x00
           flash         65     6   128    0 yes     32768  128    256  4500  4500 0x00 0x00
           lfuse          0     0     0    0 no          1    0      0  9000  9000 0x00 0x00
           hfuse          0     0     0    0 no          1    0      0  9000  9000 0x00 0x00
           efuse          0     0     0    0 no          1    0      0  9000  9000 0x00 0x00
           lock           0     0     0    0 no          1    0      0  9000  9000 0x00 0x00
           calibration    0     0     0    0 no          1    0      0     0     0 0x00 0x00
           signature      0     0     0    0 no          3    0      0     0     0 0x00 0x00

         Programmer Type : butterfly
         Description     : Atmel AppNote AVR109 Boot Loader

Connecting to programmer: .avrdude: butterfly_recv(): programmer is not responding

avrdude: butterfly_recv(): programmer is not responding
```

JeremySCook, 2023-03-01:
Has the board been programmed initially? If so, try pressing the mode button + the lower-right keyswitch to put it in programming mode. More [info is found here](https://github.com/JeremySCook/JC-Pro-Macro-2/tree/main/documentation).

JeremySCook, 2025-01-01:
Hello, I saw I hadn't closed this out, but looks like it's fixed and I hope you are enjoying your JCPM2. If you're interested, I have an experimental version using QMK firmware here: https://github.com/JeremySCook/JC-Pro-Macro-2/tree/main/code/QMK - it's rough as of now, but I think it could be really good eventually!

Closed 2025-01-01.

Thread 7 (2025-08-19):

Request: Add Documentation for Jumpers in the Reference Guide

hexbus, 2025-08-19:
### Request: Add Documentation for Jumpers in the Reference Guide

Greetings

I've been using this board since the Kickstarter days, and I was wondering if it would be possible to expand the reference guide with documentation about all the jumpers. Specifically, clarification around the following would be very helpful:

- **J1 vs J3**
  - What are the differences between them?  (Or is there none?)
  - Document pinout
  - I currently have a screen on the right-side I2C bus—can both be used at the same time?

- **J2 pinout**
  - Details for pins 9, 6, and 7
  - Document pinout
  - Clarification on 5V and GND pins

- **J4**
  - Usage (optional capacitor? auxiliary use?)

- **SCL_PU1 and SDA_PU1**
  - Both appear unpopulated—what are they intended for?

- **JP1–JP4 jumpers**
  - What each one controls
  - Example: I currently have JP3 jumped toward the bottom, and JP4 jumped toward the top

- **Voltage considerations**
  - Am I correct in assuming everything is 5V?
  - If so, for 3.3V use, would level shifters be required on all four pins of the I2C bus?

---

Thanks so much for considering adding this information!

JeremySCook, 2025-08-19:
Went ahead and added most of what you asked. Mine appears to be 3.3V, but I swapped out the Pro Micro at some point vs the Kickstarter version, and I believe that is why. You may want to test first, or it might be easier to get a different board that is 3.3V is you want to go that route.

Thanks for supporting the project!

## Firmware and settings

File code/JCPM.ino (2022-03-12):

//Example for JC Pro Macro board
//set up to work in Mac OS
//Includes support for 1306 display
//Reference: https://github.com/NicoHood/HID/blob/master/src/KeyboardLayouts/ImprovedKeylayouts.h
//Reference: https://arduinogetstarted.com/tutorials/arduino-button-long-press-short-press 

// Declare variables etc=========================================

bool SW1 = 1; //encoder button
bool SW2 = 1; //lower-left keyswitch
bool SW3 = 1;
bool SW4 = 1; 
bool SW5 = 1;
bool SW6 = 1; 
bool SW7 = 1; //upper-right keyswitch
bool SW8 = 1; 
bool SW9 = 1; //lower-right keyswitch
bool SW10 = 1; //JCPM 2 mode switch

bool underLight = 0;

bool increment = 0;
bool decrement = 0;
long oldPosition;
long newPosition;
int inputMode = 0;
int LEDLight = 1;
int LEDCircle[6] = {2, 3, 4, 5, 6, 7};
int counter = 0;
bool nascar = 0;
long newNascarTurnTime = 0;
long oldNascarTurnTime = 0;
long newBeatTime = 0;
long oldBeatTime = 0;
bool beatOn = 0;

int fanSpeed = 0;
bool fanPulse = 0;
long newPulseTime = 0;
long oldPulseTime = 0;
int fanRPM = 0;
char toneNote;

int modeArray[] = {0, 1, 3}; //adjust this array to modify sequence of modes - as written, change to {0, 1, 2, 3, 4, 5} to access all modes
int inputModeIndex = 0;
int modeArrayLength = (sizeof(modeArray) / sizeof(modeArray[0]));

// Encoder setup =============================================

#include <Encoder.h>
#include <HID-Project.h>
Encoder myEnc(1,0); //if rotation is backwards, swap 0 and 1

// Screen setup =============================================

#include <Adafruit_GFX.h>
#include <Adafruit_SSD1306.h>
#define SCREEN_WIDTH 128 // OLED display width, in pixels
#define SCREEN_HEIGHT 64 // OLED display height, in pixels
#define OLED_RESET     4 // Reset pin # (or -1 if sharing Arduino reset pin)
#define SCREEN_ADDRESS 0x3C ///< See datasheet for Address; 0x3D for 128x64, 0x3C for 128x32
Adafruit_SSD1306 display(SCREEN_WIDTH, SCREEN_HEIGHT, &Wire, OLED_RESET);

// NeoPixel setup =============================================

// NeoPixel Ring simple sketch (c) 2013 Shae Erisson
// Released under the GPLv3 license to match the rest of the
// Adafruit NeoPixel library

#include <Adafruit_NeoPixel.h>
#ifdef __AVR__
 #include <avr/power.h> // Required for 16 MHz Adafruit Trinket
#endif

// Which pin on the Arduino is connected to the NeoPixels?
#define PIN        5 // On Trinket or Gemma, suggest changing this to 1

// How many NeoPixels are attached to the Arduino?
#define NUMPIXELS 15 // Popular NeoPixel ring size

// When setting up the NeoPixel library, we tell it how many pixels,
// and which pin to use to send signals. Note that for older NeoPixel
// strips you might need to change the third parameter -- see the
// strandtest example for more information on possible values.
Adafruit_NeoPixel pixels(NUMPIXELS, PIN, NEO_GRB + NEO_KHZ800);

#define DELAYVAL 500 // Time (in milliseconds) to pause between pixels

//============================================================

void setup() {
  delay(500); //formerly longer delay to allow programming
  //Serial.begin(9600);
  pinMode(4, INPUT_PULLUP); //SW1 pushbutton (encoder button)
  pinMode(15, INPUT_PULLUP); //SW2 pushbutton
  pinMode(A0, INPUT_PULLUP); //SW3 pushbutton
  pinMode(A1, INPUT_PULLUP); //SW4 pushbutton
  pinMode(A2, INPUT_PULLUP); //SW5 pushbutton
  pinMode(A3, INPUT_PULLUP); //SW6 pushbutton
//===============new pins for JCPM

  pinMode(14, INPUT_PULLUP); //SW7 pushbutton
  pinMode(16, INPUT_PULLUP); //SW8 pushbutton
  pinMode(10, INPUT_PULLUP); //SW9 pushbutton
  pinMode(8, INPUT_PULLUP); //SW10 pushbutton - acts as mode switch

//================end new pins
  

  randomSeed(analogRead(A9));
     
  // SSD1306_SWITCHCAPVCC = generate display voltage from 3.3V internally
  if(!display.begin(SSD1306_SWITCHCAPVCC, SCREEN_ADDRESS)) {
    //Serial.println(F("SSD1306 allocation failed"));
    for(;;); // Don't proceed, loop forever
  }
  display.setRotation(2); //sets rotation 1 through 4 (2 = 180º rotation vs 4)
  display.setTextColor(SSD1306_WHITE);        // Draw white text
  display.invertDisplay(0);
  
Mouse.begin();
Keyboard.begin();
//BootKeyboard.begin(); - BootKeyboard use appears to give problems w/ Macintosh


//NeoPixel setup=========================================

  pixels.begin(); // INITIALIZE NeoPixel strip object (REQUIRED)
  pixels.clear();


  for(int i=0; i<8; i++){
    pixels.setPixelColor(i, pixels.Color(10, 0, 0));
  }
  pixels.show(); // Show results
}


void loop() {

  SW1 = digitalRead(4);
  SW2 = digitalRead(15);
  SW3 = digitalRead(A0);
  SW4 = digitalRead(A1);
  SW5 = digitalRead(A2);
  SW6 = digitalRead(A3);
  SW7 = digitalRead(14);
  SW8 = digitalRead(16);
  SW9 = digitalRead(10);
  SW10 = digitalRead(8);
  
  newPosition = myEnc.read();
  
  if (newPosition > (oldPosition + 2)) { 
    increment = 1;
    delay(5);
    oldPosition = myEnc.read();
  }
  if (newPosition < (oldPosition - 2)) {
    decrement = 1;
    delay(5);
    oldPosition = myEnc.read();
  }

//========select upload mode==================
    
  // Jump into upload mode for mode select and lower-right button
  if (SW9 == 0 && SW10 == 0) {
    screenUpload();
    delay(3600000); // I don't know why, but this delay allows to simply upload code.
  }

//=========change mode=================

   if (SW10 == 0){
      if (inputModeIndex < modeArrayLength){
        inputModeIndex++;
        inputMode = modeArray[inputModeIndex];
      }
      if (inputModeIndex == modeArrayLength){
        inputModeIndex = 0;
        inputMode = modeArray[inputModeIndex];
      }
      pixels.clear();
      pixels.show();
      SW10 = 1;
      delay(150);
    }

//======select input mode:=======

if (inputMode == 0) {
  pixels.setPixelColor(LEDCircle[LEDLight], pixels.Color(10, 0, 0));
  pixels.show(); // Show results
  volume();  
}
if (inputMode == 1) jiggler();
if (inputMode == 2) slitherIO();
if (inputMode == 3) {
  pixels.setPixelColor(LEDCircle[LEDLight], pixels.Color(0, 10, 0));
  pixels.show(); // Show results
  FCPX();
}
if (inputMode == 4) fan();
if (inputMode == 5) music();
if (inputMode == 6) textInput();

//Serial.println(inputMode);

}

void volume(){

  if (increment == 1) {
        Consumer.write(MEDIA_VOLUME_UP);
        if (LEDLight == 5) LEDLight = 0;
        else if (LEDLight < 5) LEDLight += 1;
        topPixelsClear();
        pixels.setPixelColor(LEDCircle[LEDLight], pixels.Color(10, 0, 0));
        pixels.show(); // Show results
        increment = 0;
        decrement = 0;
        //delay(10);
      }
      
  if (decrement == 1) {
        Consumer.write(MEDIA_VOLUME_DOWN);
        if (LEDLight == 0) LEDLight = 5;
        else if (LEDLight > 0) LEDLight -= 1;
        topPixelsClear();
        pixels.setPixelColor(LEDCircle[LEDLight], pixels.Color(10, 0, 0));
        pixels.show(); // Show results
        increment = 0;
        decrement = 0;
        //delay(10);
      }
  if (SW6 == 0){ //tab to next browser tab Firefox or Chrome
        Keyboard.press(KEY_LEFT_CTRL);
        Keyboard.press(KEY_TAB);          
        Keyboard.releaseAll();
        delay(50);
      }
  if (SW5 == 0){ //tab to previous browser tab Firefox or Chrome
        Keyboard.press(KEY_LEFT_SHIFT);
        Keyboard.press(KEY_LEFT_CTRL);
        Keyboard.press(KEY_TAB);
        Keyboard.releaseAll();
        delay(50);
      }
  if (SW3 == 0) {
        Consumer.write(MEDIA_PLAY_PAUSE); 
        delay(100);
      }
  if (SW4 == 0) {
        Consumer.write(MEDIA_NEXT);
        delay(50);
      }
  if (SW2 == 0) {
        Consumer.write(MEDIA_PREVIOUS);
        delay(50);
      }
  if (SW1 == 0) { //Emulate keyboard enter button when encoder knob is pressed down:
      Keyboard.press(KEY_ENTER);
      Keyboard.release(KEY_ENTER);
      delay(50);
    }
  if ((SW7 == 0) && (underLight == 0)) {        
    underLight = 1;
    for(int i=8; i<12; i++){
    pixels.setPixelColor(i, pixels.Color(255, 0, 0));
    }
    pixels.show(); // Show results
    delay(100);
  }
  else if ((SW7 == 0) && (underLight == 1)) {        
    underLight = 0;
    for(int i=8; i<12; i++){
    pixels.setPixelColor(i, pixels.Color(0, 0, 0));
    }
    pixels.show(); // Show results
    delay(100);
  }  
  if ((SW8 == 0)||(SW9 == 0)){
    fan();
  }

      
screenVolume();
}

void jiggler(){ //works with new code
  
  //Serial.print("commence to jiggling");
      //Consumer.write(MEDIA_VOLUME_UP);
      //Consumer.write(MEDIA_VOLUME_DOWN);
      long randNumber = random(-50, 50);
      long randNumber1 = random(-50, 50);
      long randNumber2 = random(-50, 50);
      Mouse.move(randNumber, randNumber1);
      delay(100);
      int xMap = map(randNumber, -50, 50, 0, 100);
      int yMap = map(randNumber1, -50, 50, 0, 100);
      int zMap = map(randNumber2, -50, 50, 0, 100);
      pixels.setPixelColor(0, pixels.Color(xMap, yMap, zMap));
      pixels.setPixelColor(2, pixels.Color(zMap,xMap,yMap));
      pixels.setPixelColor(1, pixels.Color(yMap, zMap, xMap));
      pixels.setPixelColor(3, pixels.Color(xMap, yMap, zMap));
      pixels.setPixelColor(4, pixels.Color(zMap, xMap, yMap));    
      pixels.setPixelColor(5, pixels.Color(yMap, zMap, xMap));    
      pixels.setPixelColor(6, pixels.Color(xMap, yMap, zMap));    
      pixels.setPixelColor(7, pixels.Color(zMap, xMap, yMap));  
      //pixels.setPixelColor(8, pixels.Color(yMap, zMap, xMap));                                  
      pixels.show(); // Show results

screenJiggle(); 
    
}

void slitherIO(){ //works with new code
//movement tracking
int xMovements[] = {-3, -8, -14, -16, -19, -19, -16, -14, -8, -3, 3, 8, 14, 16, 19, 19, 16, 14, 8, 3, -3};
int yMovements[] = {19, 16, 14, 8, 3, -3, -8, -14, -16, -19, -19, -16, -14, -8, -3, 3, 8, 14, 16, 19, 19};
int multiplier = 2; //changes speed of rotation

//homing routine =====================================================  
  if (SW6 == 0){
    Mouse.move(40, 10); //was 60, 0 before
    counter = 0;
    delay(250);
  }

//mouse move routine==================================================

  if (increment == 1) {
    //need a routine to loop back to zero etc to loop around the x/y movements for each increment

      for(int i=0; i< multiplier; i++){
        if (counter == 20) counter = 1;
        else if (counter < 20) ++counter;
        Mouse.move(xMovements[counter], yMovements[counter]);
        
        //Serial.print(counter); Serial.print(" "); Serial.print(xMovements[counter]); Serial.print(" "); Serial.println(yMovements[counter]);
        increment = 0;
        decrement = 0;
      }
  }
  

    if (decrement == 1) { //increment and decrement work fine individually, but don't line up when reversed
      for(int i=0; i< multiplier; i++){     
        if (counter == 0) counter = 19; 
        else if (counter > 0) --counter;       
        Mouse.move(-xMovements[counter+1], -yMovements[counter+1]);

        //Serial.print(counter); Serial.print(" "); Serial.print(-xMovements[counter+1]); Serial.print(" "); Serial.println(-yMovements[counter+1]);
        increment = 0;
        decrement = 0;
      }
  }

//worm speed input==============================

if ((SW2 == 0)||(SW3 == 0)||(SW4 ==0)){
        Keyboard.press(HID_KEYBOARD_SPACEBAR);       
        delay(5);
}

if ((SW2 == 1) && (SW3 == 1) && (SW4 == 1)){
        Keyboard.releaseAll();
        delay(5);
}

//worm auto turn input - NASCAR mode: all left turns

if ((SW5 == 0) && (nascar == 0)){
  nascar = 1;
  delay(20);
}

else if ((SW5 == 0) && (nascar ==1)){
  nascar = 0;
  delay(20);
}

if (nascar == 1){
  newNascarTurnTime = millis();
  if ((newNascarTurnTime - oldNascarTurnTime) > 200){
    decrement = 1;
    oldNascarTurnTime = newNascarTurnTime;
  }
}


screenVolume();
  
}

void FCPX(){
  
  if (increment == 1) {
        //Keyboard.press(KEY_K);
        //Keyboard.releaseAll();       
        Keyboard.press(HID_KEYBOARD_RIGHTARROW);
        Keyboard.releaseAll();
        if (LEDLight == 5) LEDLight = 0;
        else if (LEDLight < 5) LEDLight += 1;
        topPixelsClear();
        pixels.setPixelColor(LEDCircle[LEDLight], pixels.Color(0, 10, 0));
        pixels.show(); // Show results
        increment = 0;
        decrement = 0;
        //delay(50);
      }
      
  else if (decrement == 1) {
        //Keyboard.press(KEY_K);
        //Keyboard.releaseAll();  
        Keyboard.press(HID_KEYBOARD_LEFTARROW);
        Keyboard.releaseAll();
        if (LEDLight == 0) LEDLight = 5;
        else if (LEDLight > 0) LEDLight -= 1;
        topPixelsClear();
        pixels.setPixelColor(LEDCircle[LEDLight], pixels.Color(0, 10, 0));
        pixels.show(); // Show results
        increment = 0;
        decrement = 0;
        //delay(50);
      }
  else if (SW7 == 0){ //Zoom in
        Keyboard.press(KEY_LEFT_WINDOWS);
        Keyboard.press(HID_KEYBOARD_EQUALS_AND_PLUS);    
        Keyboard.releaseAll();
        delay(50);
      }
  else if (SW8 == 0){ //Zoom out
        Keyboard.press(KEY_LEFT_WINDOWS);
        Keyboard.press(HID_KEYBOARD_MINUS_AND_UNDERSCORE);    
        Keyboard.releaseAll();
        delay(50);
      }
  else if (SW4 == 0) { //fwd
        Keyboard.press(KEY_L);
        Keyboard.releaseAll();
        delay(50);
      }
  else if (SW3 == 0) { //stop
        Keyboard.press(KEY_K);
        Keyboard.releaseAll();
        delay(50);
      }
  else if (SW2 == 0) { //BACK
        Keyboard.press(KEY_J);
        Keyboard.releaseAll();
        delay(50);
      }
  else if (SW1 == 0) { //break all win + shift + b
        Keyboard.press(KEY_LEFT_WINDOWS);        
        Keyboard.press(KEY_LEFT_SHIFT);
        Keyboard.press(KEY_B);        
        Keyboard.releaseAll();
        delay(50);
      }
    else if (SW6 == 0) { //break current track win + b
        Keyboard.press(KEY_LEFT_WINDOWS);        
        Keyboard.press(KEY_B);        
        Keyboard.releaseAll();
        delay(50);
      }
    else if (SW5 == 0) { //undo
        Keyboard.press(KEY_LEFT_WINDOWS);        
        Keyboard.press(KEY_Z);        
        Keyboard.releaseAll();
        delay(50);
      }
    else if (SW9 == 0) { //backspace (delete)  
        Keyboard.press(KEY_BACKSPACE);        
        Keyboard.releaseAll();
        delay(50);
      } 
screenFCPX();
}

void fan(){
  if (SW8 == 0){
    if (fanSpeed < 5){
    ++fanSpeed;
    }
    delay(20);
  }
  if (SW9 == 0){
    if (fanSpeed > 0){
    --fanSpeed;
    }
    delay(20);
  }
int fanSpeedScaled = map(fanSpeed, 0, 5, 0, 255);
analogWrite(6, fanSpeedScaled);
//Serial.print(fanSpeed); Serial.print(" "); Serial.println(fanSpeedScaled);

if(fanPulse == 0){
  newPulseTime = millis();
  fanRPM = (newPulseTime - oldPulseTime);
  oldPulseTime = newPulseTime;
}

//screenFan();

}

void music(){

//attach small buzzer to pin 6 on aux jack
//

pinMode(7, OUTPUT);
digitalWrite(7, LOW);

  if (SW2 == 0){
    tone(6, 220, 100); //A3 
    toneNote = 'A';
  }
  else if (SW3 == 0){
    tone(6, 247, 100); //B3
    toneNote = 'B';
  }
  else if (SW4 == 0){
    tone(6, 262, 100); //C4
    toneNote = 'C';
  }  
  else if (SW9 == 0){
    tone(6, 294, 100); //D4
    toneNote = 'D';
  }
  else if (SW5 == 0){
    tone(6, 330, 100); //E4
    toneNote = 'E';
  }
  else if (SW8 == 0){
    tone(6, 349, 100); //F4
    toneNote = 'F';
  }
  else if (SW6 == 0){
    tone(6, 392, 100); //G4
    toneNote = 'G';
  }
  else if (SW7 == 0){
    tone(6, 440, 100); //A4
    toneNote = 'A';
  }
  else {
    toneNote = ' ';
  }
  
  if ((SW1 == 0) && (beatOn == 0)) {
    beatOn = 1;
    delay(100);
  }
  else if ((SW1 == 0) && (beatOn == 1)){
    beatOn = 0;
    delay(100);
  }
  
  if (beatOn == 1) {
  newBeatTime = millis();
  if ((newBeatTime - oldBeatTime) > 500){
  digitalWrite(7, HIGH);
  delay(35);
  digitalWrite(7, LOW);
    oldBeatTime = newBeatTime;
  }
  }

  if (decrement == 1){
  digitalWrite(7, HIGH);
  delay(35);
  digitalWrite(7, LOW);
  increment = 0;
  decrement = 0;
  }

  if (decrement == 1){
  digitalWrite(7, HIGH);
  delay(35);
  digitalWrite(7, LOW);
  increment = 0;
  decrement = 0;
  }

  if (increment == 1){
  digitalWrite(7, HIGH);
  delay(35);
  digitalWrite(7, LOW);
  increment = 0;
  decrement = 0;
  }
 
screenNote();
}

void textInput(){
  if (SW2 == 0){
    Keyboard.println("JC Pro Macro 2");
    delay(50);
  }
  else if (SW3 == 0){
    Keyboard.println("CAN");
    delay(50);
  }
  else if (SW4 == 0){
    Keyboard.println("DO");
    delay(50);
  }  
  else if (SW9 == 0){
    Keyboard.println("Text Input");
    delay(50);
  }
  else if (SW5 == 0){
    Keyboard.print("SW5");
    delay(50);
  }
  else if (SW8 == 0){
    Keyboard.print("SW8");
    delay(50);
  }
  else if (SW6 == 0){
    Keyboard.print("SW6");
    delay(50);
  }
  else if (SW7 == 0){
    Keyboard.print("SW7");
    delay(50);
  }
    screenTextInput();
}

//======================.96" oled screen=======================

void screenVolume(){
  display.setTextSize(1); 
  display.clearDisplay();
  display.setCursor(0,0);
  //display.println("");  
  display.println("ENCOD|     |TAB+ |LIT");
  display.println("");
  display.println("VOL- |VOL+ |TAB- |FN+");
  display.println("");
  display.println("BACK |STOP |FORW |FN-");
  display.println("");  
  //display.print(increment);
  //display.print(decrement);
  //display.print(" ");
  display.print(newPosition);
  display.print(" ");
  display.print(LEDLight);
  display.print(" ");
  display.print(SW1);
  display.print(SW2);
  display.print(SW3);
  display.print(SW4);
  display.print(SW5);
  display.print(SW6);
  display.print(SW7);
  display.print(SW8);
  display.print(SW9);
  display.print(SW10);
  display.display();
  //Serial.println(SW1);
  //delay(10);
}

void screenFan(){
  display.clearDisplay();
  display.setCursor(0,10);
  display.print("Fan ");
  display.print(fanSpeed);
  display.print(" ");
  display.println(fanPulse);
  display.print("T ");
  display.print(fanRPM);
  display.print(" ");
  display.print(inputMode);
  display.display();
  //Serial.println(SW1);
  //delay(10);
}

void screenJiggle(){
  display.setTextSize(3); 
  display.clearDisplay();
  display.setCursor(0,10);
  display.println("Rando");
  display.print("Mouse!");
  display.display();
}

void screenNote(){ //now used for notes
  display.setTextSize(3); 
  display.clearDisplay();
  display.setCursor(0,10);
  display.print("TONE ");
  display.println(toneNote);
  display.print(SW1);
  display.print(SW2);
  display.print(SW3);
  display.print(SW4);
  display.print(SW5);
  display.print(SW6);
  display.print(inputMode); 
  display.display();
  //Serial.println(SW1);
  //delay(10);
}

void screenFCPX(){
  display.setTextSize(1); 
  display.clearDisplay();
  display.setCursor(0,0);
  //display.println("");  
  display.println("FCPX |BRKA |BRK  |ZO+");
  display.println("");
  display.println("FRM- |FRM+ |UNDO |ZO-");
  display.println("");
  display.println("BACK |STOP |FORW |DEL");
  display.println("");  
  //display.println("FCPX");
  //display.print("Sh0rcut");
  display.display();
}

void screenTextInput(){
  display.setTextSize(3); 
  display.clearDisplay();
  display.setCursor(0,10);
  display.println("Text");
  display.print("Input");
  display.display();
}

void screenUpload(){
  display.setTextSize(3);
  display.clearDisplay();
  display.setCursor(0,10);
  display.println("Upload Code!");
  display.display();
}

//====================pixel helpers===============

void topPixelsClear(){
    for(int i=0; i<9; i++){
    pixels.setPixelColor(i, pixels.Color(0, 0, 0));
  }
  pixels.show(); // Show results
}

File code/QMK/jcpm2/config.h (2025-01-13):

#pragma once

// I2C Configuration
#define I2C_DRIVER I2CD1
#define I2C1_SCL_PIN D0
#define I2C1_SDA_PIN D1

// OLED Configuration
#define OLED_DISPLAY_128X64
#define OLED_DISPLAY_ADDRESS 0x3C
#define OLED_TIMEOUT 2000000

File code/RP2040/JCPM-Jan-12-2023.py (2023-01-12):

#dependencies found here https://github.com/adafruit/Adafruit_CircuitPython_Bundle on adafruit bundle
#adafruit_display_text adafruit_displayio_ssd1306 adafruit_hid neopixel adafruit_led_animation
#keycodes available: https://github.com/adafruit/Adafruit_CircuitPython_HID/tree/main/adafruit_hid

import time
import digitalio
import board
import usb_hid
#import subcode

from adafruit_hid.mouse import Mouse
from adafruit_hid.keyboard import Keyboard
from adafruit_hid.keycode import Keycode
from adafruit_hid.keyboard_layout_us import KeyboardLayoutUS
from adafruit_hid.consumer_control import ConsumerControl
from adafruit_hid.consumer_control_code import ConsumerControlCode
import random

#LED setup########################

import neopixel
from adafruit_led_animation.color import RED
from adafruit_led_animation.color import GREEN
from adafruit_led_animation.animation.solid import Solid
LEDCirclePosition = 0
LEDCircle = [2, 3, 4, 5, 6, 7]
pixel_pin = board.D5
pixel_num = 12
pixels = neopixel.NeoPixel(pixel_pin, pixel_num, brightness=0.2)



import displayio
import terminalio
from adafruit_display_text import label
import adafruit_displayio_ssd1306
displayio.release_displays()

import busio
i2c = busio.I2C(board.D3, board.D2)

display_bus = displayio.I2CDisplay(i2c, device_address=0x3C)


WIDTH = 128
HEIGHT = 64  # Change to 64 if needed
BORDER = 5 # is this needed??

display = adafruit_displayio_ssd1306.SSD1306(display_bus, width=WIDTH, height=HEIGHT, rotation=180)

# Make the display context
splash = displayio.Group()
display.show(splash)

color_bitmap = displayio.Bitmap(WIDTH, HEIGHT, 1)
color_palette = displayio.Palette(1)
color_palette[0] = 0xFFFFFF  # White

# Draw a label
text = "ENCOD:    TAB+ XXXX"
text_area = label.Label(terminalio.FONT, text=text, color=0xFFFFFF, x=5, y=5)
splash.append(text_area)
text = "VOL- VOL+ TAB- FNX"
text_area = label.Label(terminalio.FONT, text=text, color=0xFFFFFF, x=5, y=20)
splash.append(text_area)
text = "BACK STOP FORW FNX"
text_area = label.Label(terminalio.FONT, text=text, color=0xFFFFFF, x=5, y=35)
splash.append(text_area)

#rotary setup
# SPDX-FileCopyrightText: 2018 Kattni Rembor for Adafruit Industries
#
# SPDX-License-Identifier: MIT

import rotaryio
import board
encoder = rotaryio.IncrementalEncoder(board.D0, board.D1)
last_position = encoder.position

########################

SW2_PIN = board.SCK
SW3_PIN = board.A0
SW4_PIN = board.A1
SW5_PIN = board.A2
SW6_PIN = board.A3
SW7_PIN = board.MISO
SW8_PIN = board.MOSI
SW9_PIN = board.D10
SW10_PIN = board.D8 #Mode pin

keyboard = Keyboard(usb_hid.devices)
cc = ConsumerControl(usb_hid.devices)
mouse = Mouse(usb_hid.devices)

randomMode = 0

SW2 = digitalio.DigitalInOut(SW2_PIN)
SW2.direction = digitalio.Direction.INPUT
SW2.pull = digitalio.Pull.UP

SW3 = digitalio.DigitalInOut(SW3_PIN)
SW3.direction = digitalio.Direction.INPUT
SW3.pull = digitalio.Pull.UP

SW4 = digitalio.DigitalInOut(SW4_PIN)
SW4.direction = digitalio.Direction.INPUT
SW4.pull = digitalio.Pull.UP

SW5 = digitalio.DigitalInOut(SW5_PIN)
SW5.direction = digitalio.Direction.INPUT
SW5.pull = digitalio.Pull.UP

SW6 = digitalio.DigitalInOut(SW6_PIN)
SW6.direction = digitalio.Direction.INPUT
SW6.pull = digitalio.Pull.UP

SW7 = digitalio.DigitalInOut(SW7_PIN)
SW7.direction = digitalio.Direction.INPUT
SW7.pull = digitalio.Pull.UP

SW8 = digitalio.DigitalInOut(SW8_PIN)
SW8.direction = digitalio.Direction.INPUT
SW8.pull = digitalio.Pull.UP

SW9 = digitalio.DigitalInOut(SW9_PIN)
SW9.direction = digitalio.Direction.INPUT
SW9.pull = digitalio.Pull.UP

SW10 = digitalio.DigitalInOut(SW10_PIN)
SW10.direction = digitalio.Direction.INPUT
SW10.pull = digitalio.Pull.UP

##Keys Function###########################

def keys():
    if not SW2.value:
        print("switch 2 pressed")
        cc.send(ConsumerControlCode.SCAN_PREVIOUS_TRACK)
        time.sleep(0.2)

    if not SW3.value:
        print("switch 3 pressed")
        cc.send(ConsumerControlCode.PLAY_PAUSE)
        time.sleep(0.2)

    if not SW4.value:
        print("switch 4 pressed")
        cc.send(ConsumerControlCode.SCAN_NEXT_TRACK)
        time.sleep(0.2)

    if not SW5.value:
        print("switch 5 pressed")
        keyboard.press(Keycode.LEFT_CONTROL, Keycode.LEFT_SHIFT, Keycode.TAB)
        time.sleep(0.2)
        keyboard.release(Keycode.LEFT_CONTROL, Keycode.LEFT_SHIFT, Keycode.TAB)

    if not SW6.value:
        print("switch 6 pressed")
        keyboard.press(Keycode.LEFT_CONTROL, Keycode.TAB)
        time.sleep(0.2)
        keyboard.release(Keycode.LEFT_CONTROL, Keycode.TAB)

    if not SW7.value:
        print("switch 7 pressed")
        keyboard.press(Keycode.F)
        time.sleep(0.2)
        keyboard.release(Keycode.F)

    if not SW8.value:
        print("switch 8 pressed")
        keyboard.press(Keycode.G)
        time.sleep(0.2)
        keyboard.release(Keycode.G)

    if not SW9.value:
        print("switch 9 pressed")
        keyboard.press(Keycode.H)
        time.sleep(0.2)
        keyboard.release(Keycode.H)

    if not SW10.value:
        global randomMode
        if randomMode == 0:
            randomMode = 1
        elif randomMode == 1:
            randomMode = 0
        print("switch 10 pressed, randomMode = ", randomMode)
        time.sleep(0.2)

def encoder1():
    global last_position
    global LEDCircle
    global LEDCirclePosition

    position = encoder.position
    delta = 0

    if last_position is None or position != last_position:
        #print('encoder postion', position)

        delta = position - last_position
        last_position = position

    if delta > 0:
        #print("encoder down - volume decrease")
        cc.send(ConsumerControlCode.VOLUME_DECREMENT)
        for LEDLoop in range(6):
            pixels[LEDCircle[LEDLoop]] = (0, 0, 0) #Clear Key LEDs
        if LEDCirclePosition == 0:
            LEDCirclePosition = 5
        elif LEDCirclePosition > 0:
            LEDCirclePosition = LEDCirclePosition - 1

    if delta < 0:
        #print("endoder up - volume increase")
        cc.send(ConsumerControlCode.VOLUME_INCREMENT)
        for LEDLoop in range(6):
            pixels[LEDCircle[LEDLoop]] = (0, 0, 0) #Clear Key LEDs
        if LEDCirclePosition == 5:
            LEDCirclePosition = 0
        elif LEDCirclePosition < 5:
            LEDCirclePosition = LEDCirclePosition + 1

    pixels[LEDCircle[LEDCirclePosition]] = (55, 0, 0)

#print('LEDCirclePosition', LEDCirclePosition)
#time.sleep(.2)

def randomMouseRoutine():
    print("random mouse movement")
    randX = random.randint(-20,20)
    randY = random.randint(-20, 20)
    print (randX, "  ", randY)
    mouse.move(x = randX, y = randY)

while True:

    keys()
    encoder1()
    if randomMode:
        randomMouseRoutine()

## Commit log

2022-02-27 Correcting solder pads for JP4 and JP3
    Correcting solder pads for JP4 and JP3
2022-03-12 Added code to encoder knob to emulate Enter button
2022-04-10 Create DanH-case
